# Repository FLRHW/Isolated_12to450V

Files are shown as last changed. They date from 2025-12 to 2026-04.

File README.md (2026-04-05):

<p align="center" width="100%">
  <a href="https://github.com/FLRHW/Isolated_12to450V/actions/workflows/ci.yaml">
    
  </a>
</p>

<p align="center" width="100%">
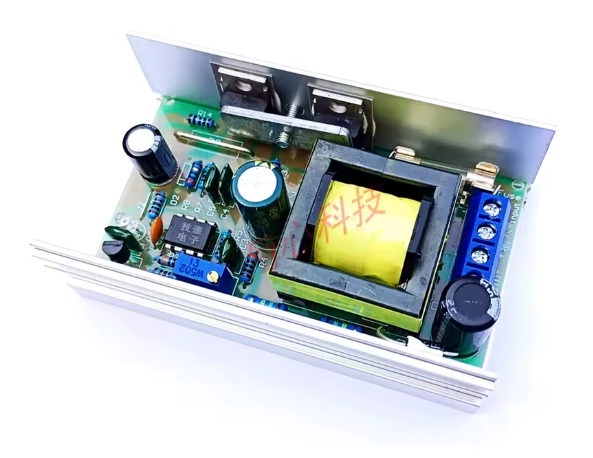
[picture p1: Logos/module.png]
    
</p>

***

<p align="center">
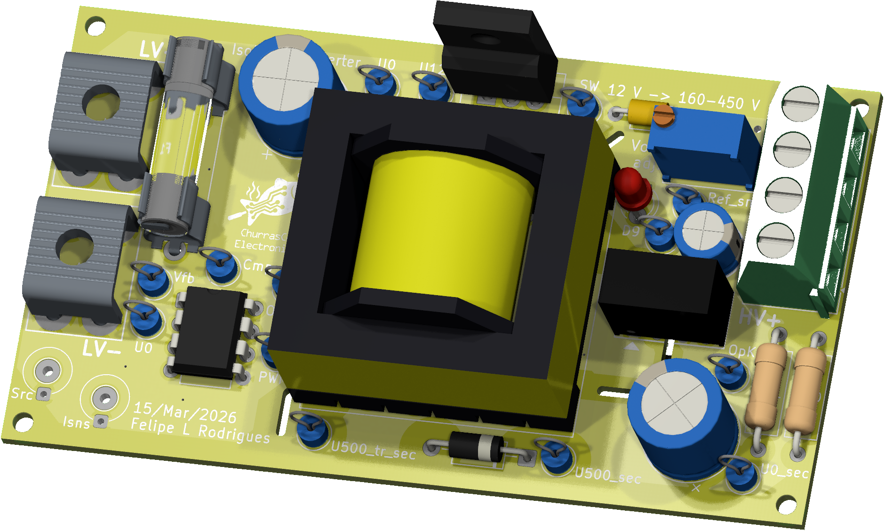
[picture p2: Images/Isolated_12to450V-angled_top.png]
3D Top Angled
  
&nbsp; &nbsp; &nbsp; &nbsp;
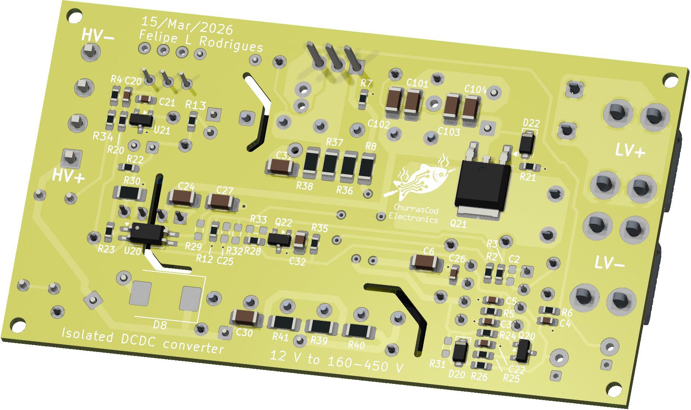
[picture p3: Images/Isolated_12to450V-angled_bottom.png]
3D Bottom Angled
  
</p>

***

# **Isolated step-up module**
This repository contains KiCad schematic and PCB layout of a step-up module prototype, isolated, capable of producing outputs in the range of 160 V to 450 V from a 12 V supply.

## Project overview
This project documents the conversion of a commercial non-isolated step-up module originally purchased from AliExpress into isolated.

## Origin and scope
Original hardware: generic module purchased from AliExpress (exact vendor and listing may change over time, the following terms can help finding similar modules: "70W DC-DC 12V 24V To 200V-450V Voltage Adjustable Boost Power Converter Nixie Clock Tube Amplifier Capacitor Charging").  

Redesigned hardware: new schematic and PCB layout, but several parts from the original module have been reused (controller, transformer, connector, fuse and its holder, power MOSFET, output diode, trim-pot, power resistors and electrolytic capacitors). 

Status: prototype, partially tested. Not affiliated with, endorsed by, or supported by the original manufacturer or seller.

Contents: KiCad design files and supporting documentation.

## Intended use
This repository is intended for:
* Educational use and study of the circuit
* Repair, modification, or replacement of compatible hardware
* Integration into hobby or research projects, subject to any third‑party IP that may apply in your jurisdiction. Users are responsible for checking any patent, copyright, or regulatory constraints that may apply to their own use

## License
The KiCad design files and documentation in this repository are released under the CERN Open Hardware Licence v2 – Permissive (CERN‑OHL‑P‑2.0). SPDX identifier: CERN-OHL-P-2.0 See the LICENSE file for the full legal text and conditions.  

In short and non‑legal terms, you are free to use, modify, manufacture, and distribute hardware based on these files, provided you respect attribution requirements and the terms in the license.

## Trademarks and third‑party rights
All product names, logos, and brands of the original module are the property of their respective owners and are not included or licensed here.  

Any reference to third‑party marks is purely descriptive and does not imply endorsement or affiliation.  

If you are the rights holder for the original hardware and have concerns about this documentation, please open an issue in the repository.

## Safety and disclaimer
* The author takes no responsibility for any injury, death or damage arising from the use, direct or indirect, of the design or otherwise any information from this repository
* You shall not build this or any prototype based on this design unless you are absolutely sure of your abilities dealing with this type of circuit
* High voltage can cause injury, death, or damage to equipment. Ensure appropriate protections and testing procedures are followed
* Use it at your own risk. Always review the schematic, layout, and component ratings before using it
* The design is provided as is, with no warranty of any kind

## Contributing
Contributions are welcome.

***

## DIRECTORY STRUCTURE
    │
    ├─ Computations       # Misc calculations
    ├─ HTML               # HTML files for generated webpage
    ├─ Images             # Pictures and renders
    │
    ├─ kibot_resources    # External resources for KiBot
    │  ├─ colors          # Color theme for KiCad
    │  ├─ fonts           # Fonts used in the project
    │  ├─ scripts         # External scripts used with KiBot
    │  └─ templates       # Templates for KiBot generated reports
    │
    ├─ kibot_yaml         # KiBot YAML config files
    ├─ KiRI               # KiRI (PCB diff viewer) files
    │
    ├─ lib                # KiCad footprint and symbol libraries
    │  ├─ 3d_models       # Component 3D models
    │  ├─ lib_fp          # Footprint libraries
    │  └─ lib_sym         # Symbol libraries
    │
    ├─ Logos              # Logos
    │
    ├─ Manufacturing      # Assembly and fabrication documents
    │  ├─ Assembly        # Assembly documents (BoM, pos, notes)
    │  │
    │  └─ Fabrication     # Fabrication documents (ZIP, notes)
    │     ├─ Drill Tables # CSV drill tables
    │     └─ Gerbers      # Gerbers
    │
    ├─ Reports            # Reports for ERC/DRC
    ├─ Schematic          # PDF of schematic
    ├─ Templates          # Title block templates
    └─ Testing
       └─ Testpoints      # Testpoints tables

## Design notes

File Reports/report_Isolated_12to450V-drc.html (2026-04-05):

Logo

(https://github.com/INTI-CMNB/KiBot/) | DRC report for Isolated_12to450V
| PCB: Isolated_12to450V Revision: 3.0.1 Date: 2026-04-05T18:37:05+0000 KiCad Version: 9.0.7 | Errors: 0 (+1 excluded) Warnings: 9 Total: 9 (+1 excluded)

Violations

Type | Description | Details
lib_footprint_issues | The current configuration does not include the footprint library 'Personal'. | @(109.601 mm, 81.026 mm): Footprint TP36
lib_footprint_issues | The current configuration does not include the footprint library 'Personal'. | @(151.003 mm, 66.294 mm): Footprint TR1
lib_footprint_issues | The current configuration does not include the footprint library 'Personal'. | @(111.633 mm, 68.326 mm): Footprint J21
lib_footprint_issues | The current configuration does not include the footprint library 'Personal'. | @(116.078 mm, 83.301861 mm): Footprint TP35
lib_footprint_issues | The current configuration does not include the footprint library 'Personal'. | @(147.828 mm, 48.768 mm): Footprint R9
lib_footprint_issues | The current configuration does not include the footprint library 'Personal'. | @(173.736 mm, 66.294 mm): Footprint Mod20
lib_footprint_issues | The current configuration does not include the footprint library 'Personal'. | @(111.633 mm, 52.451 mm): Footprint J20
lib_footprint_issues | The current configuration does not include the footprint library 'Personal'. | @(120.523 mm, 54.991 mm): Footprint F1
lib_footprint_mismatch | Footprint 'LED_D3.0mm' does not match copy in library 'LED_THT'. | @(168.021 mm, 54.864 mm): Footprint D9
courtyards_overlap | Courtyards overlap | @(189.0 mm, 42.027 mm): Footprint H2 @(185.928 mm, 61.816 mm): Footprint J1

Generated by KiBot (https://github.com/INTI-CMNB/KiBot/) v1.8.6

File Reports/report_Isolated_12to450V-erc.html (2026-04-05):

Logo

(https://github.com/INTI-CMNB/KiBot/) | ERC report for Isolated_12to450V
| Schematic: Isolated_12to450V Revision: 3.0.1 Date: 2026-04-05T18:37:03+0000 KiCad Version: 9.0.7 | Errors: 0 Warnings: 33 Total: 33

Sheet / (Isolated_12to450V.kicad_sch)

Type | Description | Details
lib_symbol_issues | The current configuration does not include the symbol library 'personal' | @(0.2286 mm, 0.9652 mm): Symbol P32 [Cosmetic_PWR]
lib_symbol_issues | The current configuration does not include the symbol library 'personal' | @(0.6604 mm, 1.1684 mm): Symbol P30 [Cosmetic_PWR]
lib_symbol_issues | The current configuration does not include the symbol library 'personal' | @(0.7874 mm, 1.1684 mm): Symbol P31 [Cosmetic_PWR]
footprint_link_issues | The current configuration does not include the footprint library 'Personal'. | @(1.3462 mm, 0.4572 mm): Symbol J20 [Screw_Terminal_01x01]
footprint_link_issues | The current configuration does not include the footprint library 'Personal'. | @(1.3462 mm, 0.6858 mm): Symbol J21 [Screw_Terminal_01x01]
lib_symbol_issues | The current configuration does not include the symbol library 'personal' | @(1.0668 mm, 1.1684 mm): Symbol P20 [Cosmetic_PWR]
footprint_link_issues | The current configuration does not include the footprint library 'Personal'. | @(1.5367 mm, 0.4572 mm): Symbol F1 [Fuse]
lib_symbol_issues | The current configuration does not include the symbol library 'personal' | @(1.1684 mm, 1.1684 mm): Symbol P21 [Cosmetic_PWR]
lib_symbol_issues | The current configuration does not include the symbol library 'personal' | @(1.5748 mm, 0.9144 mm): Symbol P24 [Cosmetic_PWR]
lib_symbol_issues | The current configuration does not include the symbol library 'personal' | @(1.8796 mm, 0.4318 mm): Symbol P26 [Cosmetic_PWR_SRC]
lib_symbol_issues | The current configuration does not include the symbol library 'personal' | @(1.5748 mm, 1.1684 mm): Symbol P106 [Cosmetic_PWR_SRC]
lib_symbol_issues | The current configuration does not include the symbol library 'personal' | @(1.3208 mm, 1.8288 mm): Symbol P27 [Cosmetic_PWR_SRC]
lib_symbol_issues | The current configuration does not include the symbol library 'personal' | @(1.8542 mm, 1.397 mm): Symbol U1 [UC3845]
lib_symbol_issues | The current configuration does not include the symbol library 'personal' | @(2.032 mm, 1.27 mm): Symbol P22 [Cosmetic_PWR]
lib_symbol_issues | The current configuration does not include the symbol library 'personal' | @(2.4638 mm, 0.8382 mm): Symbol P23 [Cosmetic_PWR]
lib_symbol_issues | The current configuration does not include the symbol library 'personal' | @(2.413 mm, 1.2446 mm): Symbol P105 [Cosmetic_PWR]
footprint_link_issues | The current configuration does not include the footprint library 'Personal'. | @(2.3114 mm, 1.6764 mm): Symbol TP35 [OscTestpoint]
lib_symbol_issues | The current configuration does not include the symbol library 'personal' | @(2.3114 mm, 1.6764 mm): Symbol TP35 [OscTestpoint]
lib_symbol_issues | The current configuration does not include the symbol library 'personal' | @(3.0988 mm, 0.5588 mm): Symbol P101 [Cosmetic_IN]
lib_symbol_issues | The current configuration does not include the symbol library 'personal' | @(2.9591 mm, 1.0922 mm): Symbol P102 [Cosmetic_OUT]
footprint_link_issues | The current configuration does not include the footprint library 'Personal'. | @(2.7178 mm, 1.6764 mm): Symbol TP36 [OscTestpoint]
lib_symbol_issues | The current configuration does not include the symbol library 'personal' | @(2.7178 mm, 1.6764 mm): Symbol TP36 [OscTestpoint]
footprint_link_issues | The current configuration does not include the footprint library 'Personal'. | @(3.2004 mm, 0.635 mm): Symbol TR1 [TR_12to450V_alixp_inv]
lib_symbol_issues | The current configuration does not include the symbol library 'personal' | @(3.2004 mm, 0.635 mm): Symbol TR1 [TR_12to450V_alixp_inv]
footprint_link_issues | The current configuration does not include the footprint library 'Personal'. | @(2.8194 mm, 1.6637 mm): Symbol R9 [R]
footprint_link_issues | The current configuration does not include the footprint library 'Personal'. | @(3.2004 mm, 1.0668 mm): Symbol TR1 [TR_12to450V_alixp_inv]
lib_symbol_issues | The current configuration does not include the symbol library 'personal' | @(3.2004 mm, 1.0668 mm): Symbol TR1 [TR_12to450V_alixp_inv]
lib_symbol_issues | The current configuration does not include the symbol library 'personal' | @(2.921 mm, 1.905 mm): Symbol P25 [Cosmetic_PWR]
footprint_link_issues | The current configuration does not include the footprint library 'Personal'. | @(3.2004 mm, 1.9812 mm): Symbol Mod20 [WB____S-1W_long]
lib_symbol_issues | The current configuration does not include the symbol library 'personal' | @(3.2004 mm, 1.9812 mm): Symbol Mod20 [WB____S-1W_long]
lib_symbol_issues | The current configuration does not include the symbol library 'personal' | @(3.556 mm, 1.3716 mm): Symbol P8 [Cosmetic_PWR]
lib_symbol_issues | The current configuration does not include the symbol library 'personal' | @(3.7338 mm, 0.9906 mm): Symbol P28 [Cosmetic_PWR_SRC]
lib_symbol_issues | The current configuration does not include the symbol library 'personal' | @(3.5052 mm, 1.905 mm): Symbol P29 [Cosmetic_PWR_SRC]

Generated by KiBot (https://github.com/INTI-CMNB/KiBot/) v1.8.6

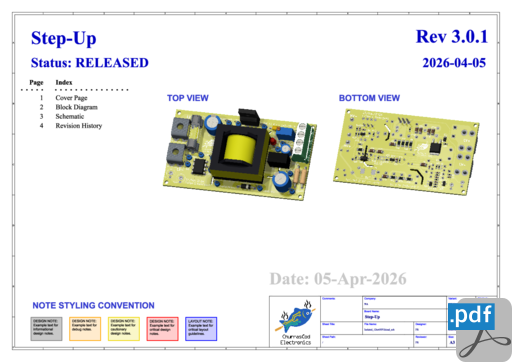
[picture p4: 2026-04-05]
HTML/images/cat_pdf_schematic_Isolated_12to450V-schematic.png

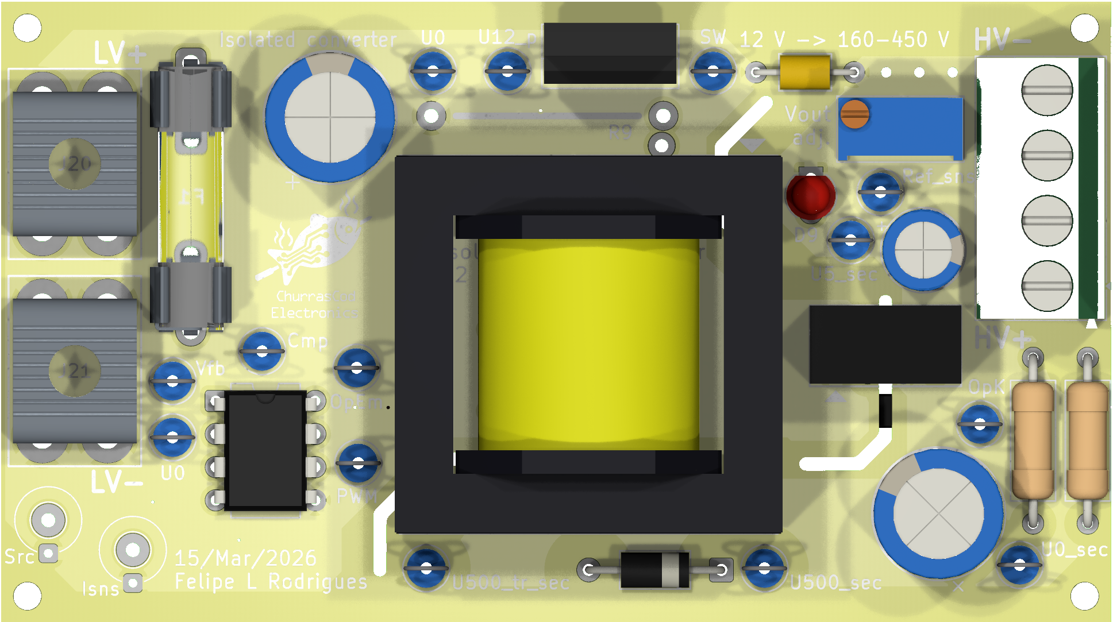
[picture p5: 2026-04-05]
Images/Isolated_12to450V-top.png

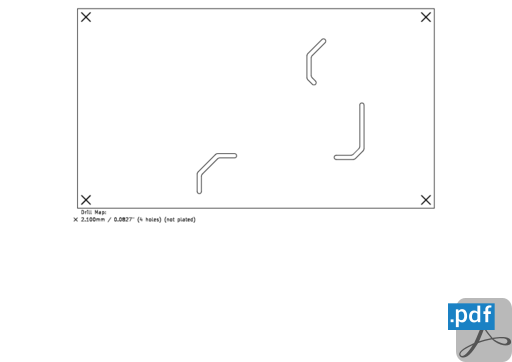
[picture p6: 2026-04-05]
HTML/images/cat_pdf_drill_map_Isolated_12to450V-NPTH_drill_map.png

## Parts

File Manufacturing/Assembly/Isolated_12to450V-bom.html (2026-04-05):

 | Bill of Materials
 | Schematic: Isolated_12to450V Variant: RELEASED Revision: 3.0.1 Date: 2026-02-07 KiCad Version: 9.0.7+1 | Component Groups: 50 Component Count: 75 (per PCB) Fitted Components: 68 (per PCB) Number of PCBs: 1 Total Components: 68 (for 1 PCBs)
Row | Quantity Per PCB | References | Value | Datasheet | Footprint | Description | Manufacturer | Manufacturer Part Number | Supplier Part Number
1 | 1 | C21 | 100p | ~ | C_0603_1608Metric_Pad1.08x0.95mm_HandSolder | Unpolarized capacitor
2 | 1 | C30 | 220p | ~ | C_1206_3216Metric_Pad1.33x1.80mm_HandSolder | Unpolarized capacitor
3 | 2 | C3 C4 | 1n | ~ | C_0603_1608Metric_Pad1.08x0.95mm_HandSolder | Unpolarized capacitor
4 | 1 | C29 | 1.5n | ~ | C_Axial_L3.8mm_D2.6mm_P7.50mm_Horizontal | Unpolarized capacitor
5 | 1 | C31 | 2.7n | ~ | C_1206_3216Metric_Pad1.33x1.80mm_HandSolder | Unpolarized capacitor
6 | 1 | C22 | 10n | ~ | C_0603_1608Metric_Pad1.08x0.95mm_HandSolder | Unpolarized capacitor
7 | 3 | C5 C20 C26 | 100n | ~ | C_0603_1608Metric_Pad1.08x0.95mm_HandSolder | Unpolarized capacitor
8 | 1 | C32 | 1u | ~ | C_0805_2012Metric_Pad1.18x1.45mm_HandSolder | Unpolarized capacitor
9 | 7 | C6 C24 C27 C101 C102 C103 C104 | 4.7u | ~ | C_1206_3216Metric_Pad1.33x1.80mm_HandSolder | Unpolarized capacitor
10 | 1 | C8 | 10u | ~ | CP_Radial_D10.0mm_P5.00mm | Polarized capacitor
11 | 1 | C28 | 100u | ~ | CP_Radial_D6.3mm_P2.50mm | Polarized capacitor
12 | 1 | C7 | 1000u | ~ | CP_Radial_D10.0mm_P5.00mm | Polarized capacitor
13 | 1 | D22 | BZT52B15 | https://diotec.com/tl_files/diotec/files/pdf/datasheets/bzt52b2v4.pdf | D_SOD-123F | 500mW Zener Diode, SOD-123F
14 | 1 | D9 | LED | ~ | LED_D3.0mm | Light emitting diode
15 | 1 | D20 | PMEG4010CEH | https://assets.nexperia.com/documents/data-sheet/PMEG4010CEH_PMEG4010CEJ.pdf | D_SOD-123F | 40V, 1A very low Vf MEGA Schottky barrier rectifier, SOD-123F
16 | 1 | D4 | UF4007 | ~ | D_A-405_P10.16mm_Horizontal | Diode
17 | 1 | F1 | 10A | ~ | Fuse_5x20mm_w_holders | Fuse
18 | 1 | J1 | Screw_Terminal_01x04 | ~ | TerminalBlock_Phoenix_MKDS-1,5-4_1x04_P5.00mm_Horizontal | Generic screw terminal, single row, 01x04, script generated (kicad-library-utils/schlib/autogen/connector/) |  | Generic screw terminal
19 | 2 | J20 J21 | T44007 | ~ | T44007 | Generic screw terminal, single row, 01x01, script generated (kicad-library-utils/schlib/autogen/connector/) |  | T44007
20 | 1 | Mod20 | WB2405S-1W |  | WB___S-1W |  | RLT | WB2405S-1W
21 | 1 | Q20 | BC817 | https://www.onsemi.com/pub/Collateral/BC818-D.pdf | SOT-23 | 0.8A Ic, 45V Vce, NPN Transistor, SOT-23
22 | 1 | Q22 | BC857 | https://www.onsemi.com/pub/Collateral/BC860-D.pdf | SOT-23 | 0.1A Ic, 45V Vce, PNP Transistor, SOT-23
23 | 1 | Q1 | HY1707 | ~ | TO-220F-3_Vertical | N-MOSFET transistor, gate/drain/source
24 | 1 | Q21 | SUD50P06-15 | https://www.vishay.com/docs/68940/sud50p06.pdf | TO-252-2 | -50A Id, -60V Vds, TrenchFET P-Channel Power MOSFET, 15mOhm Ron, 165nC Qg, -55 to 150 °C, TO-252-2
25 | 2 | R28 R34 | 0 | ~ | R_0603_1608Metric_Pad0.98x0.95mm_HandSolder | Resistor
26 | 1 | R9 | 13.7m | ~ | Shunt_alixp_module | Resistor
27 | 1 | R8 | 20 | ~ | R_1206_3216Metric_Pad1.30x1.75mm_HandSolder | Resistor
28 | 3 | R36 R37 R38 | 33 | ~ | R_1206_3216Metric_Pad1.30x1.75mm_HandSolder | Resistor
29 | 1 | R23 | 470 | ~ | R_0603_1608Metric_Pad0.98x0.95mm_HandSolder | Resistor |  | RC0603FR-07470RL
30 | 4 | R30 R39 R40 R41 | 470 | ~ | R_1206_3216Metric_Pad1.30x1.75mm_HandSolder | Resistor |  | RC1206JR-07470RL
31 | 2 | R6 R13 | 1k | ~ | R_0603_1608Metric_Pad0.98x0.95mm_HandSolder | Resistor
32 | 1 | R12 | 1k2 | ~ | R_0603_1608Metric_Pad0.98x0.95mm_HandSolder | Resistor
33 | 2 | R22 R25 | 2k2 | ~ | R_0603_1608Metric_Pad0.98x0.95mm_HandSolder | Resistor
34 | 1 | R4 | 2k7 | ~ | R_0603_1608Metric_Pad0.98x0.95mm_HandSolder | Resistor
35 | 2 | R24 R26 | 4k7 | ~ | R_0603_1608Metric_Pad0.98x0.95mm_HandSolder | Resistor
36 | 1 | R7 | 5k1 | ~ | R_0603_1608Metric_Pad0.98x0.95mm_HandSolder | Resistor
37 | 3 | R2 R3 R21 | 10k | ~ | R_0603_1608Metric_Pad0.98x0.95mm_HandSolder | Resistor
38 | 1 | R5 | 15k | ~ | R_0603_1608Metric_Pad0.98x0.95mm_HandSolder | Resistor
39 | 2 | R20 R35 | 100k | ~ | R_0603_1608Metric_Pad0.98x0.95mm_HandSolder | Resistor
40 | 2 | R10 R11 | 240k | ~ | R_Axial_DIN0309_L9.0mm_D3.2mm_P12.70mm_Horizontal | Resistor
41 | 1 | TR1 | Custom_1:19.5 |  | Tr12to450V_Alixp
42 | 1 | U20 | TCMT1108 | http://www.vishay.com/docs/83510/tcmt1100.pdf | SOP-4_4.4x2.6mm_P1.27mm | Optocoupler, Vce 70V, CTR 130-260%, Viso 3750V (RMS), SOP-4 |  | TCMT1108
43 | 1 | U21 | TL431M |  | SOT-23 | Shunt Regulator, SOT-23 | FOSAN | TL431M-0.3%-6AF
44 | 1 | U1 | UC3845 |  | DIP-8_W7.62mm
45 | 1 | VR1 | 5k | ~ | Potentiometer_Bourns_3296W_Vertical | Trim-potentiometer
Row | Quantity Per PCB | References | Value | Datasheet | Footprint | Description | Manufacturer | Manufacturer Part Number | Supplier Part Number
1 | 2 | C2 C25 | 1n | ~ | C_0603_1608Metric_Pad1.08x0.95mm_HandSolder | Unpolarized capacitor
2 | 1 | D8 | S15M | ~ | D_SMC | Diode
3 | 2 | R32 R33 | 0 | ~ | R_0603_1608Metric_Pad0.98x0.95mm_HandSolder | Resistor
4 | 1 | R29 | 1k | ~ | R_0603_1608Metric_Pad0.98x0.95mm_HandSolder | Resistor
5 | 1 | R31 | 2k2 | ~ | R_0603_1608Metric_Pad0.98x0.95mm_HandSolder | Resistor
Color reference for columns:
KiCad Fields (default)
Generated Fields
User Fields
Empty Fields

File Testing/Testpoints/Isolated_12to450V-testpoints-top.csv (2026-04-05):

Ref. | Net | X [mm] | Y [mm]
TP9 | Sec_ref_sns | 71.76 | 89.03
TP10 | Sec_OpK | 79.38 | 71.25
TP20 | SW | 58.93 | 98.30
TP23 | PWM | 31.76 | 68.26
TP24 | Vfb | 17.53 | 74.55
TP25 | Comp | 24.39 | 76.83
TP26 | OpEm | 31.63 | 75.56
TP27 | U500_sec | 62.87 | 60.20
TP28 | U0_sec | 82.43 | 60.45
TP30 | U500_tr_sec | 36.96 | 60.20
TP31 | U12_p | 43.19 | 98.30
TP32 | U0 | 17.53 | 70.23
TP33 | U0 | 37.47 | 98.30
TP34 | U5_sec | 69.48 | 85.34
TP35 | Isns,U0 | 14.48 | 60.34
TP36 | Src,U0 | 8.01 | 62.61

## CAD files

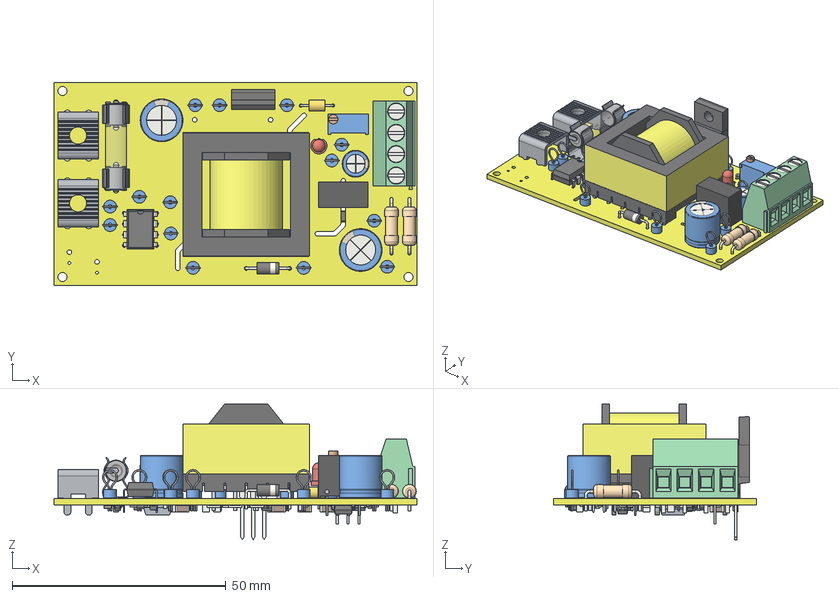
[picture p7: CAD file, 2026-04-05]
3D/Isolated_12to450V.step
85.0 x 47.5 x 31.8 mm
R_Axial_DIN0309_L9.0mm_D3.2mm_P12.70mm_Horizontal x 2
Trafo_12to450V_module
TestPoint_Loop_D3.50mm_Drill0.9mm_Beaded x 14
C_Axial_L3.8mm_D2.6mm_P7.50mm_Horizontal
TerminalBlock_Phoenix_MKDS-1,5-4_1x04_P5.00mm_Horizontal
T44007_base x 2
CP_Radial_D10.0mm_P5.00mm x 2
TO-220F-3_Vertical
WB____S-1W
CP_Radial_D6.3mm_P2.50mm
DIP-8_W7.62mm
Potentiometer_Bourns_3296W_Vertical
Endcaps
Glass_body
fuse_holder x 2
D_A-405_P10.16mm_Horizontal
LED_D3.0mm
C_0603_1608Metric x 7
R_1206_3216Metric x 8
C_1206_3216Metric x 9
Isolated_12to450V 1.39.1
R_0603_1608Metric x 18
SOT-23 x 3
D_SOD-123F x 2
SOP-4_4.4x2.6mm_P1.27mm
C_0805_2012Metric
kibot_cr949vfv_PCB

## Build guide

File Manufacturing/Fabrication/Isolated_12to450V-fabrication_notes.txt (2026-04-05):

FABRICATION NOTES (UNLESS OTHERWISE SPECIFIED)

1)	FABRICATE PER IPC-6012A CLASS 2.

2)	OUTLINE DEFINED IN SEPARATE GERBER FILE WITH
	"Edge_Cuts.GBR" SUFFIX.

	DIMENSIONS SHOWN ON THIS DRAWING ARE FOR REFERENCE ONLY.

3)	SEE SEPARATE DRILL FILES WITH ".DRL" SUFFIX 
	FOR HOLE LOCATIONS.

	SELECTED HOLE LOCATIONS SHOWN ON THIS DRAWING 
	ARE FOR REFERENCE ONLY.

4)	SURFACE FINISH: HAL LEAD-FREE

5)	SOLDERMASK ON BOTH SIDES OF THE BOARD SHALL 
	BE LPI, COLOR YELLOW.

6)	SILK SCREEN LEGEND TO BE APPLIED PER LAYER 
	STACKUP USING WHITE NON-CONDUCTIVE EPOXY INK.

7)	ALL VIAS ARE TENTED ON BOTH SIDES UNLESS 
	SOLDERMASK OPENED IN GERBER.

8)	VENDOR SHOULD FOLLOW ROHS COMPLIANT PROCESS 
	AND Pb FREE FOR MANUFACTURING

9)	PCB MATERIAL REQUIREMENTS:

	A.	FLAMMABILITY RATING MUST MEET OR EXCEED 
		UL94V-0 REQUIREMENTS.
	B.	Tg 170 C OR EQUIVALENT.
	C.	EQUIVALENT MATERIAL SHALL BE RoHS COMPLIANT, 
		HALOGEN FREE AND APPROVED BY BUYER.

10)	DESIGN GEOMETRY MINIMUM FEATURE SIZES:

	BOARD SIZE				85.000 × 47.540 mm
	BOARD THICKNESS		1.600 mm
	TRACE WIDTH			0.300 mm
	TRACE TO TRACE		0.020 mm
	MIN. HOLE (PTH)			0.250 mm
	MIN. HOLE (NPTH)		2.100 mm
	ANNULAR RING			0.150 mm
	COPPER TO HOLE		0.200 mm
	COPPER TO EDGE		0.250 mm
	HOLE TO HOLE			0.254 mm

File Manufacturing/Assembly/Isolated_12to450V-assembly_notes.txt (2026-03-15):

ASSEMBLY NOTES (UNLESS OTHERWISE SPECIFIED)

1)	DO NOT POPULATE PARTS MARKED WITH A RED CROSS.

2)	IF CONFLICTING INFORMATION IS FOUND BETWEEN THE ASSEMBLY
	FILE AND BOM, BOM SHOULD BE USED AS THE MAIN SOURCE.

3)	DOT/CHAMFER/TRIANGLE/CROSS IDENTIFY PIN #1 LOCATION.

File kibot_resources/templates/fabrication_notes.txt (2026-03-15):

FABRICATION NOTES (UNLESS OTHERWISE SPECIFIED)

1)	FABRICATE PER IPC-6012A CLASS 2.

2)	OUTLINE DEFINED IN SEPARATE GERBER FILE WITH
	"Edge_Cuts.GBR" SUFFIX.

	DIMENSIONS SHOWN ON THIS DRAWING ARE FOR REFERENCE ONLY.

3)	SEE SEPARATE DRILL FILES WITH ".DRL" SUFFIX 
	FOR HOLE LOCATIONS.

	SELECTED HOLE LOCATIONS SHOWN ON THIS DRAWING 
	ARE FOR REFERENCE ONLY.

4)	SURFACE FINISH: ${pcb_finish_cap}

5)	SOLDERMASK ON BOTH SIDES OF THE BOARD SHALL 
	BE LPI, COLOR ${solder_mask_color_text_cap}.

6)	SILK SCREEN LEGEND TO BE APPLIED PER LAYER 
	STACKUP USING ${silk_screen_color_text_cap} NON-CONDUCTIVE EPOXY INK.

7)	ALL VIAS ARE TENTED ON BOTH SIDES UNLESS 
	SOLDERMASK OPENED IN GERBER.

8)	VENDOR SHOULD FOLLOW ROHS COMPLIANT PROCESS 
	AND Pb FREE FOR MANUFACTURING

9)	PCB MATERIAL REQUIREMENTS:

	A.	FLAMMABILITY RATING MUST MEET OR EXCEED 
		UL94V-0 REQUIREMENTS.
	B.	Tg 170 C OR EQUIVALENT.
	C.	EQUIVALENT MATERIAL SHALL BE RoHS COMPLIANT, 
		HALOGEN FREE AND APPROVED BY BUYER.

10)	DESIGN GEOMETRY MINIMUM FEATURE SIZES:

	BOARD SIZE				${bb_w_mm} × ${bb_h_mm} mm
	BOARD THICKNESS		${thickness_mm} mm
	TRACE WIDTH			${track_mm} mm
	TRACE TO TRACE		${clearance_mm} mm
	MIN. HOLE (PTH)			${drill_pth_real_mm} mm
	MIN. HOLE (NPTH)		${drill_npth_real_mm} mm
	ANNULAR RING			${oar_mm} mm
	COPPER TO HOLE		${c2h_mm} mm
	COPPER TO EDGE		${c2e_mm} mm
	HOLE TO HOLE			${h2h_mm} mm
#?stackup and impedance_controlled

#?stackup and impedance_controlled
11)	REFER TO IMPEDANCE TABLE FOR IMPEDANCE CONTROL REQUIREMENTS.
#?stackup and impedance_controlled

#?stackup and impedance_controlled
12)	CONFIRM SPACE WIDTHS AND SPACINGS.

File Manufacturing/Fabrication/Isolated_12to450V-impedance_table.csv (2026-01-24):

Transmission Line | Impedance [ohms] | Tolerance [ohms] | Layer | Trace Width [mm] | Gap [mm] | Ref. Layers
NA | - | - | - | - | - | -

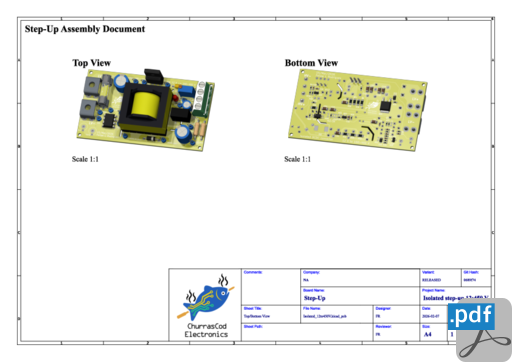
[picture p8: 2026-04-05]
HTML/images/cat_pdf_assembly_Isolated_12to450V-assembly.png

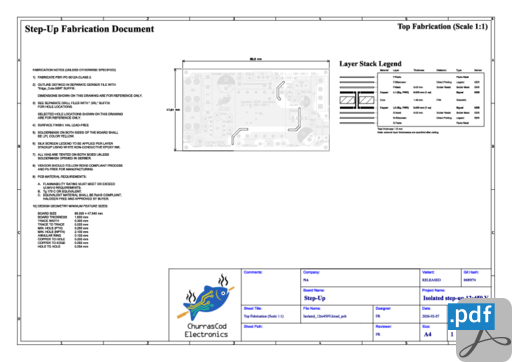
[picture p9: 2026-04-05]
HTML/images/cat_pdf_fabrication_Isolated_12to450V-fabrication.png

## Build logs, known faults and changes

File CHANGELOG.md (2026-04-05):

# Changelog

## [Unreleased]

## [3.0.1] - 2026-04-05

### Added power on LED

Updated manufacturing docs
Added some MPNs so different parts are on separate BOM lines

## [3.0.0] - 2026-03-15

### C3 and R15 updated for shorter dead time

R26 increased to reduce artificial ramp
R31 added as alternative for artificial ramp
C4 updated to 1 nF
C20, C21 and R20 updated (slower compensation)
R3 increased (gain = 1 on error amp.)
C2 not fitted (secondary side compensation only)
D23 removed
Default optocoupler supply swapped R29->R28
R32 and R34 added to facilitate testing
Added snubber accross Q1 and D4
Enlarged R8, C6, C24 and C27 footprints
Silk typos (HV+/HV-) and R9 footprint fixed
Decreased R23 to prevent overvoltage at low load
Soft start circuit moved to primary side
Added D9 to support series connected modules
Added MLCCs in parallel with C7 to improve decoupling 

## [2.0.0] - 2026-02-07

### Added R29 as feed-forward option

Isolated primary ("LV") and secondary ("HV") sides
Updated reverse polarity protection (based on P-channel MOSFET)
Added dedicated connectors for supply input
Replaced C6 (100 uF elco -> 4.7 uF + 100 nF MLCCs)
Added C25 to support testing
Replaced packages (U1: DIP-8 -> SOIC-8; U21: TO-92 -> SOT-23)
Replaced U20 (SH816 -> TCMT1108)
Replaced Q20 (2N2222 -> BC817)
Reworked slope compensation
Updated F1 footprint and 3D model
Added part number to D4
Updated Mod20 decoupling and added R30 as load
Added testpoints
Added clearance rules

## [1.0.0] - 2026-01-24

### Cloned non-isolated design revision 1.1.0 as a working base.

Updated R10 and R11 to 240 kΩ (cloned design incorrectly used 140 kΩ).
Updated U1 to UC3845 (cloned design incorrectly used UC3843).
Reworked feedback loop to include opto-coupler while keeping the same reference on both sides to facilitate testing / reuse of original board.
Added two options of slope compensation / ramp injection (from U1 RT_CT pin and from U1 OUTPUT pin).
Adjusted R2 to 10 kΩ, R3 to 5 kΩ and C2 to 1 nF to improve behaviour (output swaps from bursts to 0 % duty periodically).
Added soft-start (D21, R27 and C23).
Increased C5 to 100 nF.
Adjusted C4 to 1.5 nF and R6 to 1 kΩ (similar time constant) to facilitate ramp injection.
Updated parts placement where suitable to reuse existing layout and added an auxiliary perf-board to accomodate the new parts.

[Unreleased]: https://github.com/FLRHW/Isolated_12to450V/compare/3.0.1...HEAD

[3.0.1]: https://github.com/FLRHW/Isolated_12to450V/compare/3.0.0...3.0.1

[3.0.0]: https://github.com/FLRHW/Isolated_12to450V/compare/2.0.0...3.0.0

[2.0.0]: https://github.com/FLRHW/Isolated_12to450V/compare/1.0.0...2.0.0

[1.0.0]: https://github.com/FLRHW/Isolated_12to450V/compare/f8c9afb6a11647257dfa5ab046e95b1ec53fcfd7...1.0.0

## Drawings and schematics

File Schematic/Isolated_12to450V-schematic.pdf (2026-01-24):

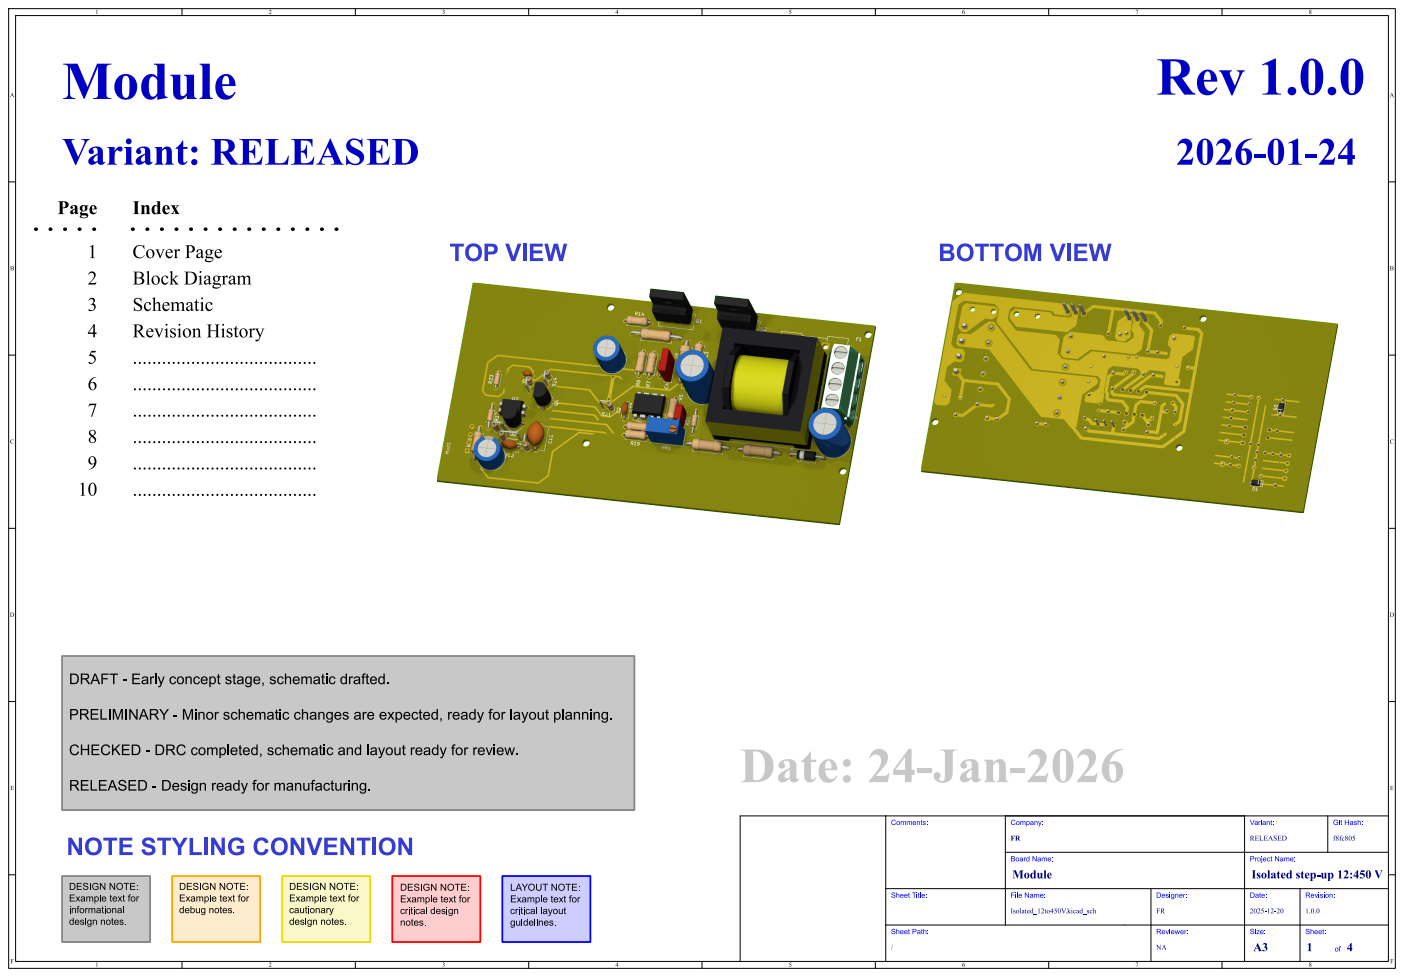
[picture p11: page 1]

PRELIMINARY - Minor schematic changes are expected, ready for layout planning.

CHECKED - DRC completed, schematic and layout ready for review.

RELEASED - Design ready for manufacturing.
NOTE STYLING CONVENTION

Revision: 1.0.0 Date: Project Name: 2025-12-20 Reviewer: NADesigner:

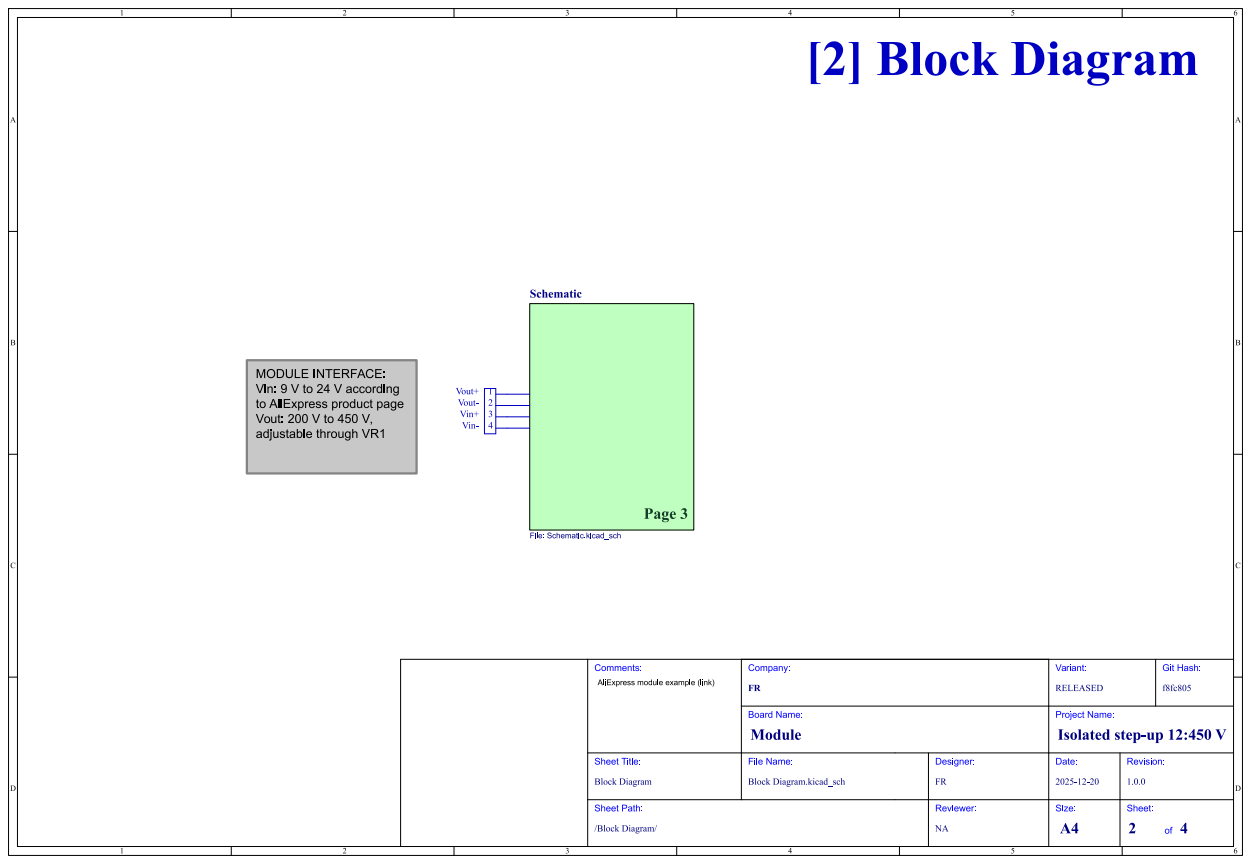
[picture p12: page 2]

File: Schematic.kicad_sch MODULE INTERFACE:
Vin: 9 V to 24 V according
to AliExpress product page
Vout: 200 V to 450 V,
adjustable through VR1

AliExpress module example (link) (https://www.aliexpress.com/item/1005006040711629.html)

/Block Diagram/ Sheet Path: Block Diagram

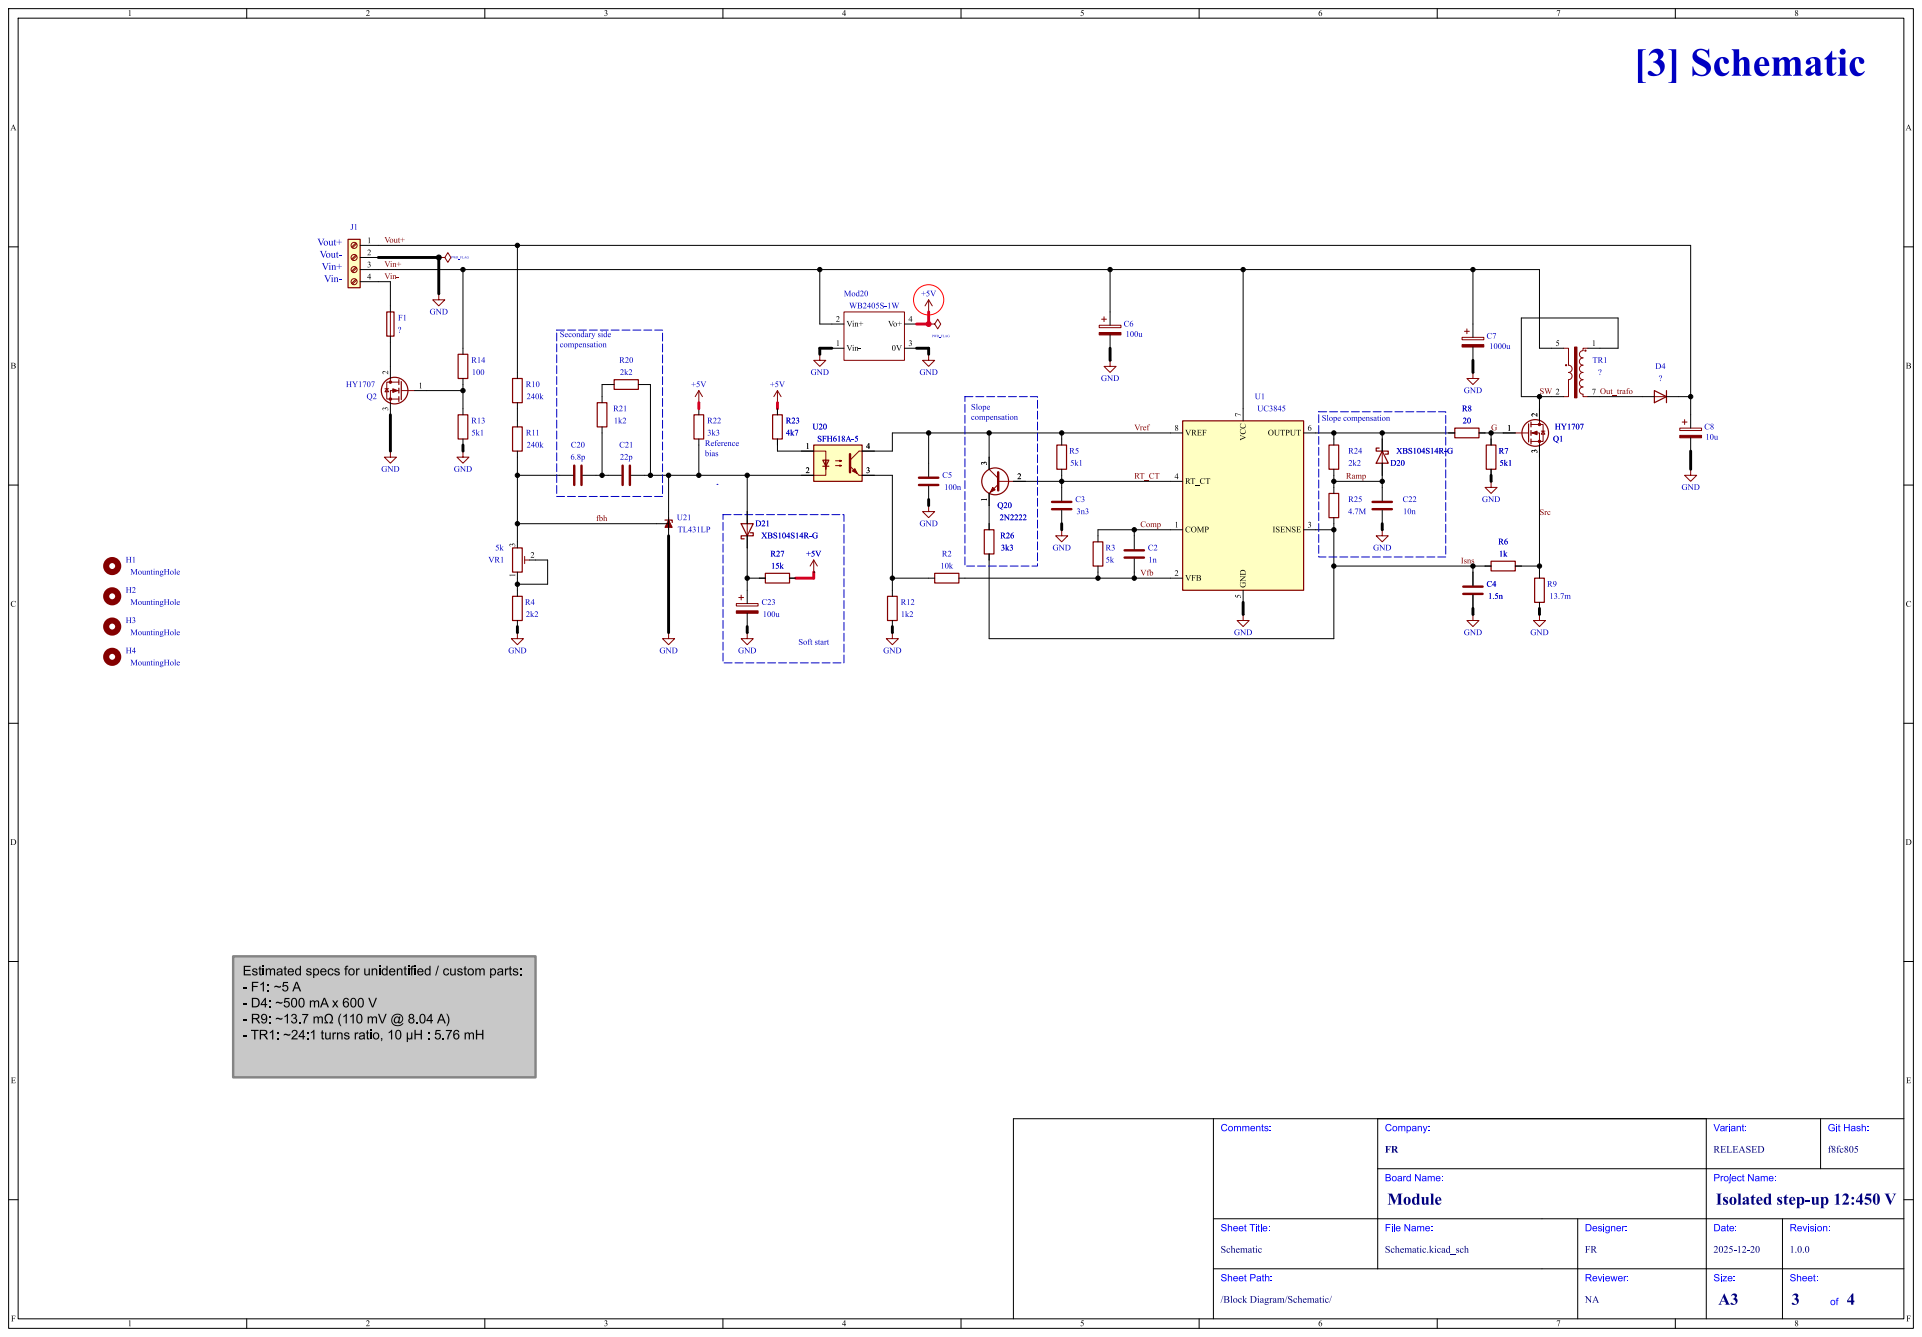
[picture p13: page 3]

- TR1: ~24:1 turns ratio, 10 þÿ¼H: 5.76 mH

Revision: 1.0.0 Date: Project Name: 2025-12-20 Reviewer: NADesigner:

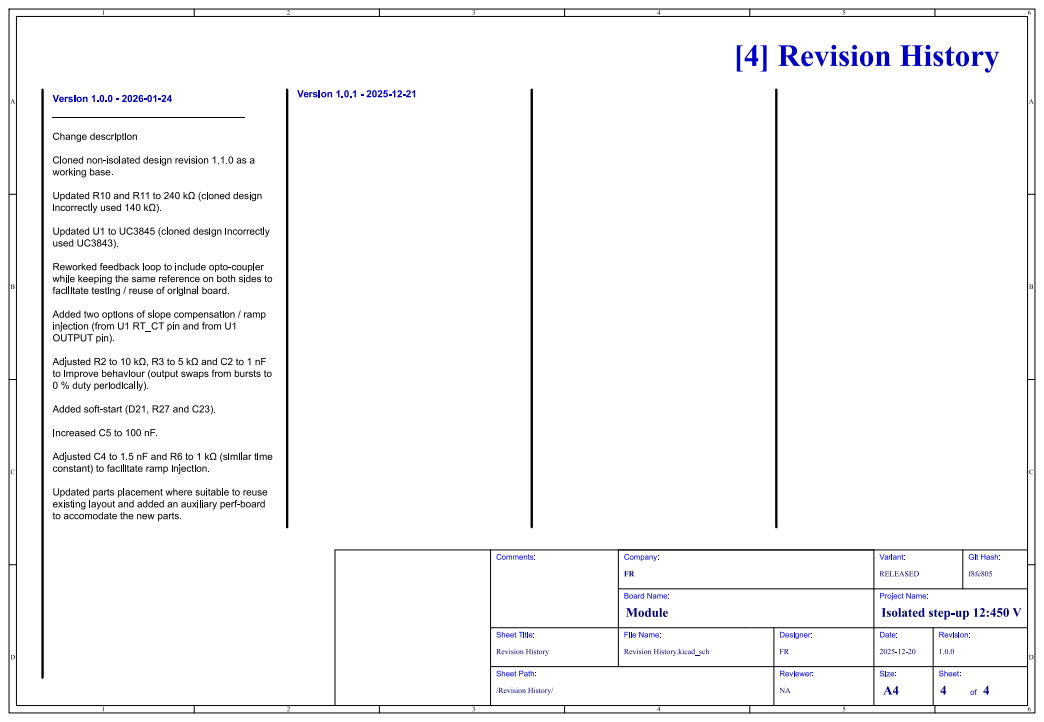
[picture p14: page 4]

Cloned non-isolated design revision 1.1.0 as a working base.

Updated R10 and R11 to 240 þÿk©(cloned design
incorrectly used 140 þÿk©).

Updated U1 to UC3845 (cloned design incorrectly
used UC3843).

Reworked feedback loop to include opto-coupler
while keeping the same reference on both sides to
facilitate testing / reuse of original board.

Added two options of slope compensation / ramp
injection (from U1 RT_CT pin and from U1
OUTPUT pin).

Adjusted R2 to 10 þÿk©, R3 to 5 þÿk©and C2 to 1 nF
to improve behaviour (output swaps from bursts to
0 % duty periodically).

Added soft-start (D21, R27 and C23).

Adjusted C4 to 1.5 nF and R6 to 1 þÿk©(similar time
constant) to facilitate ramp injection.

Updated parts placement where suitable to reuse
existing layout and added an auxiliary perf-board
to accomodate the new parts.

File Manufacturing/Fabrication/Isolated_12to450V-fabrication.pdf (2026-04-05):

# Top Fabrication (Scale 1:1) Step-Up Fabrication Document

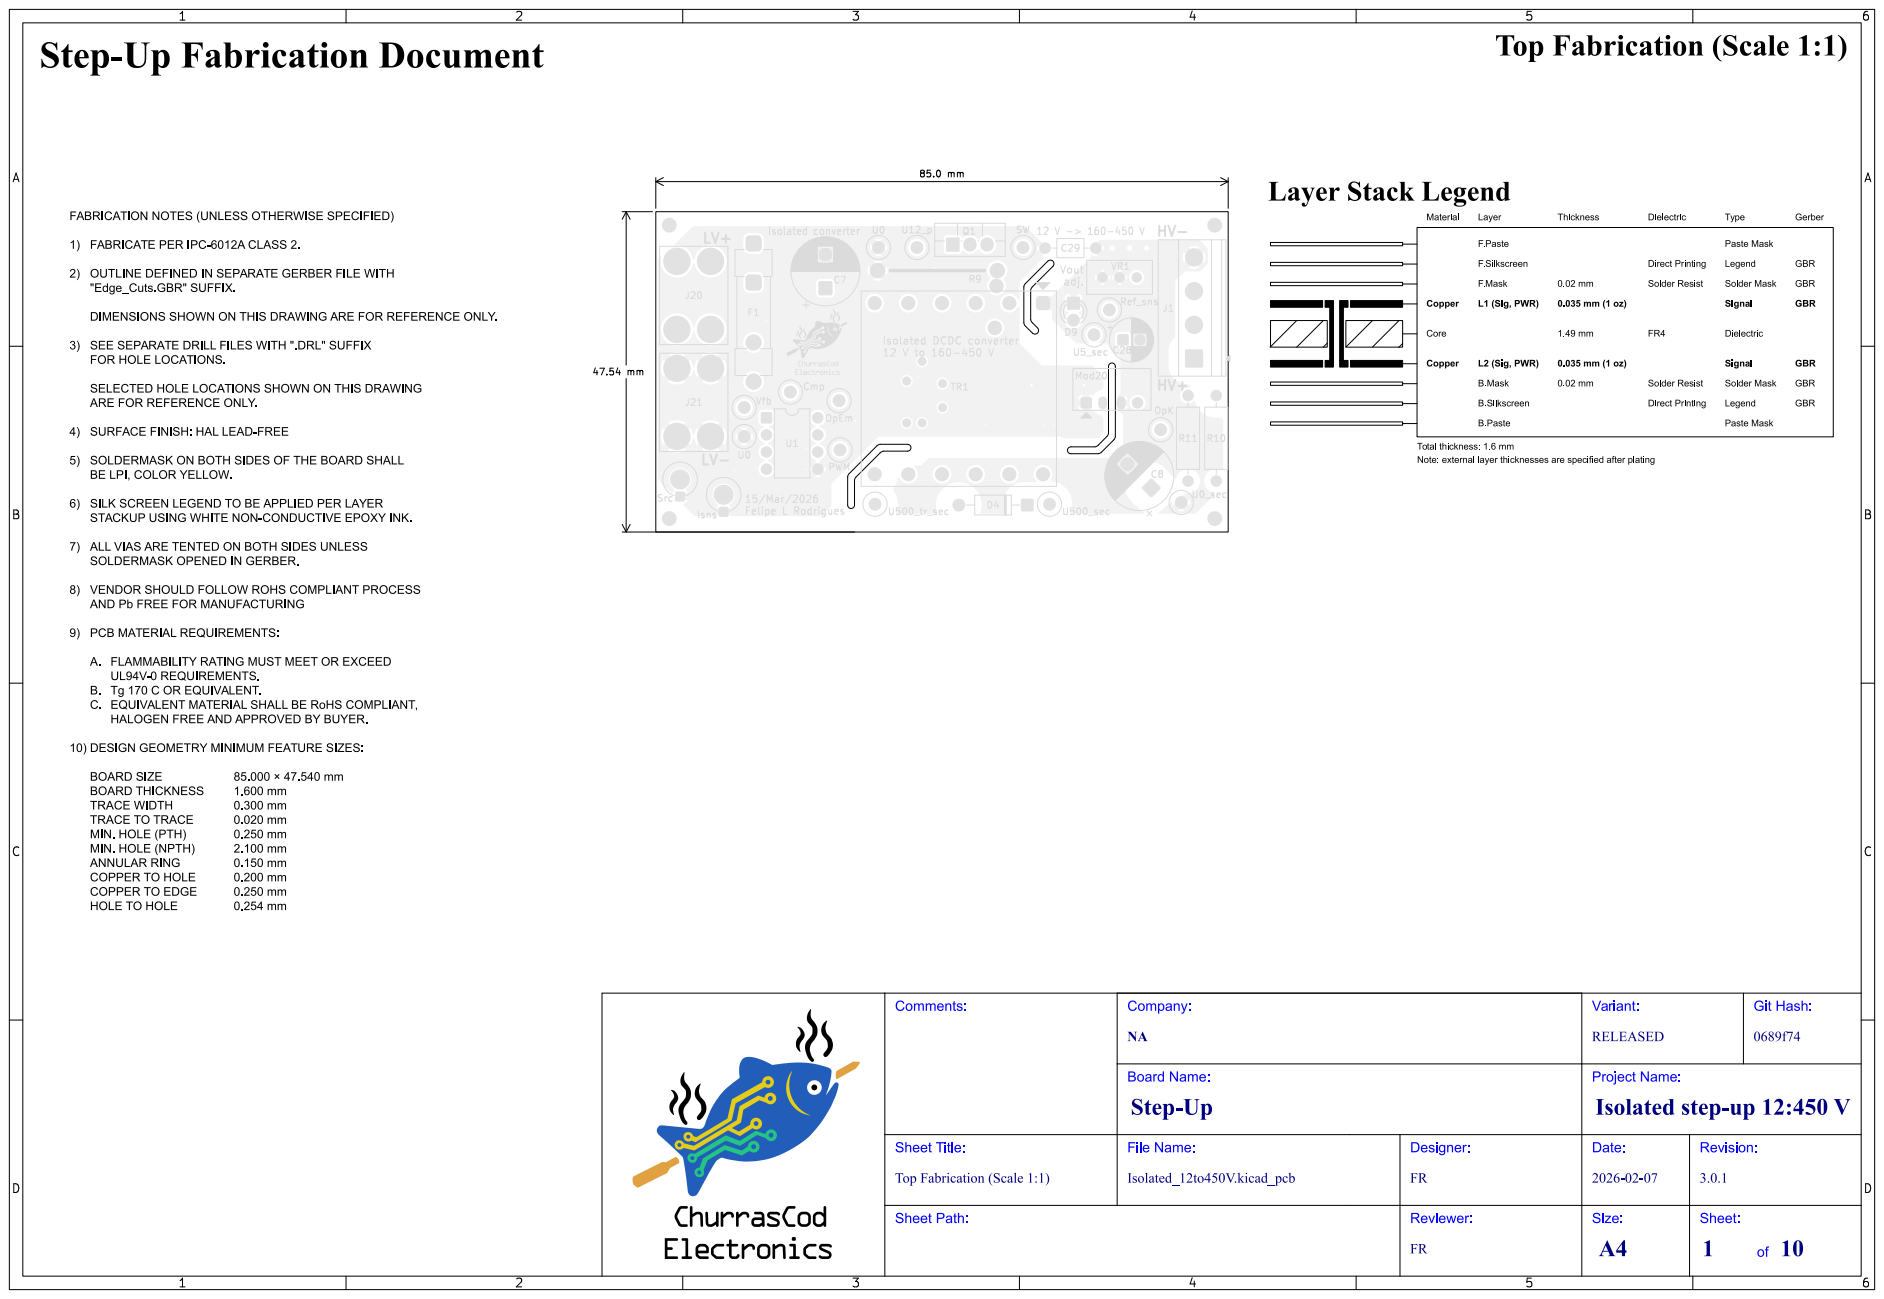
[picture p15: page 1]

# Bottom Fabrication (Scale 1:1) Step-Up Fabrication Document

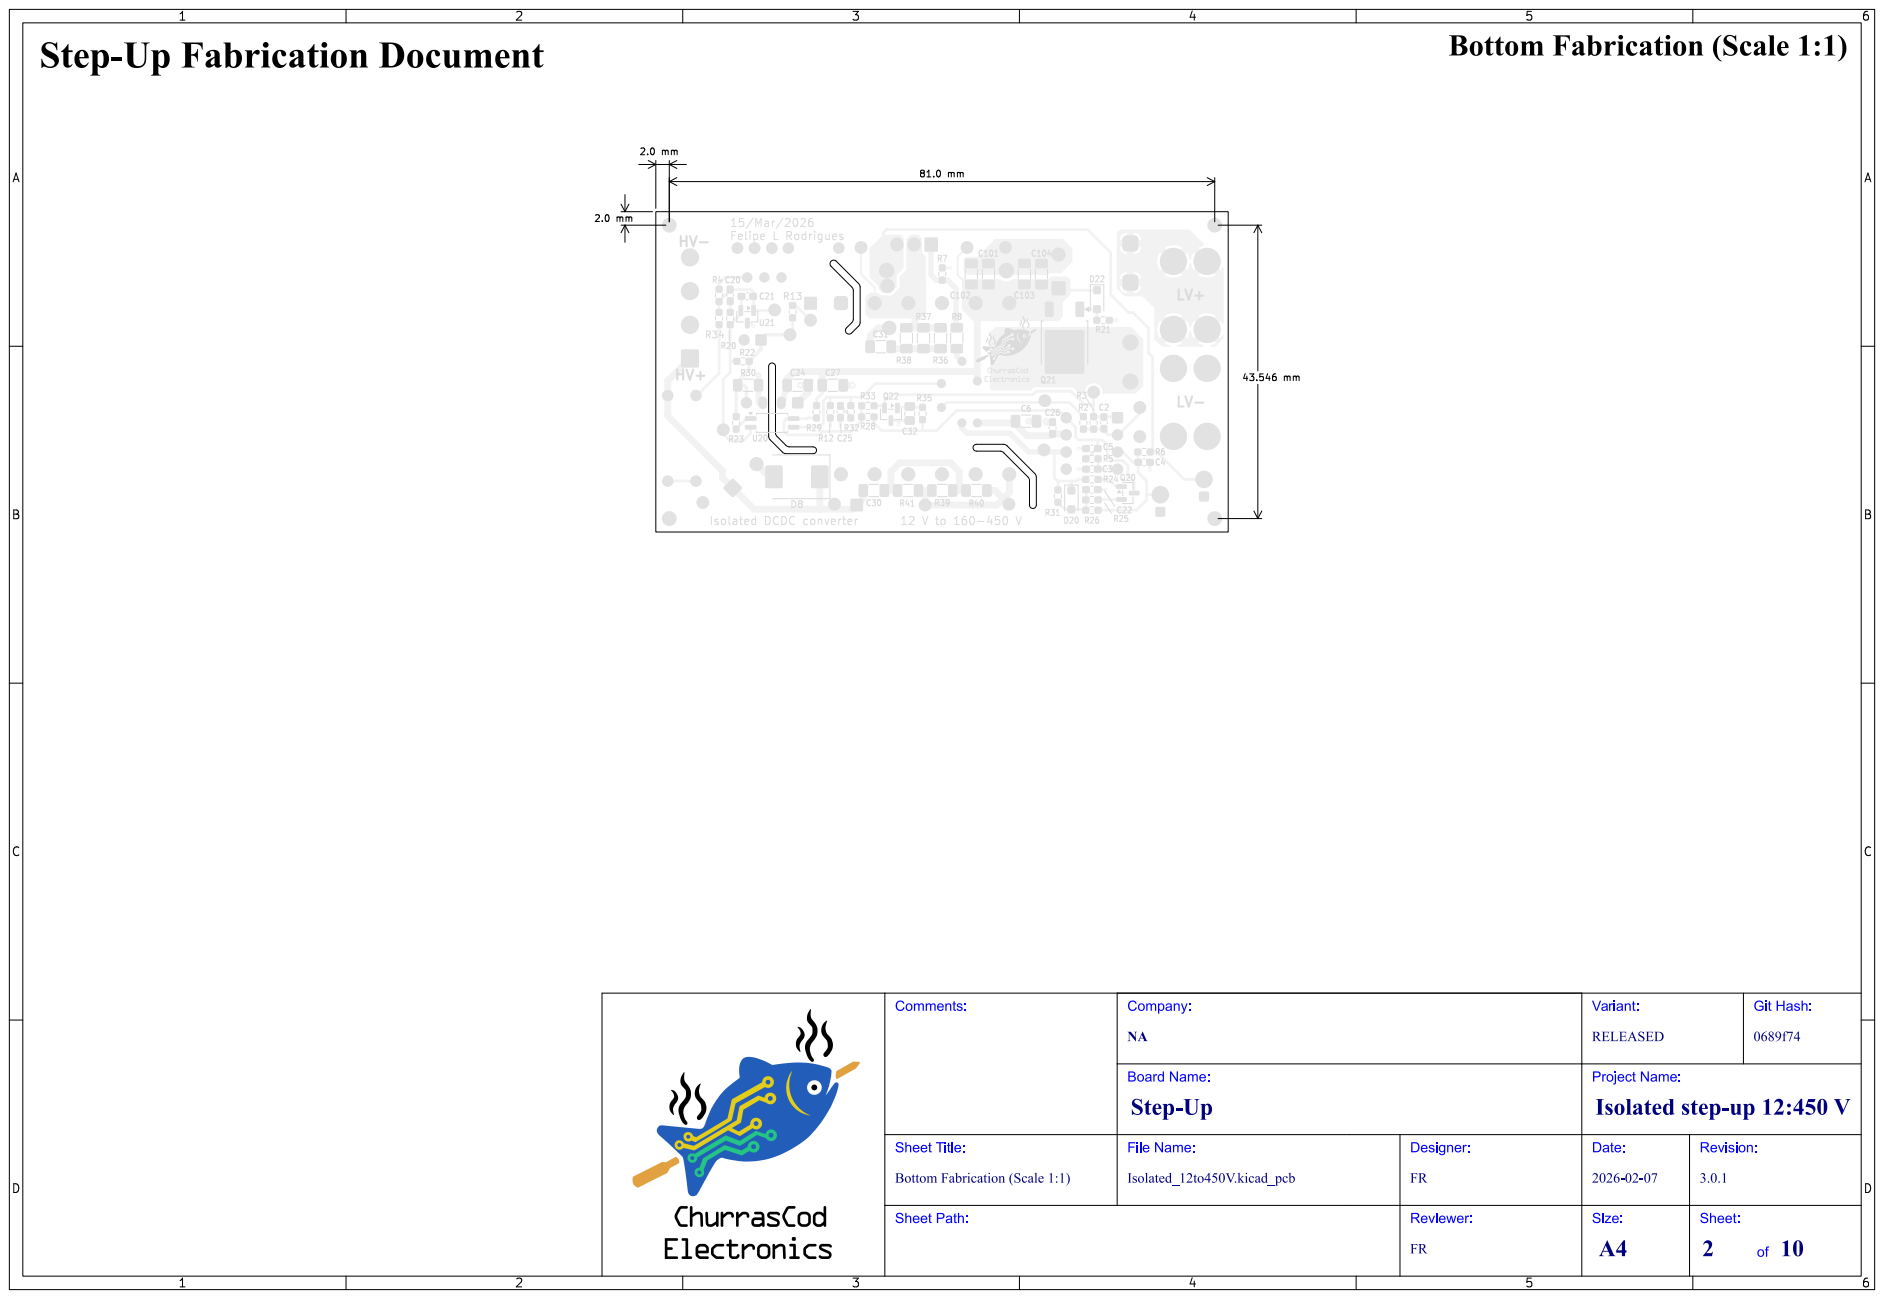
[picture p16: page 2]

# Drill Drawing L1 - L4 (Scale 1:1) Step-Up Fabrication Document

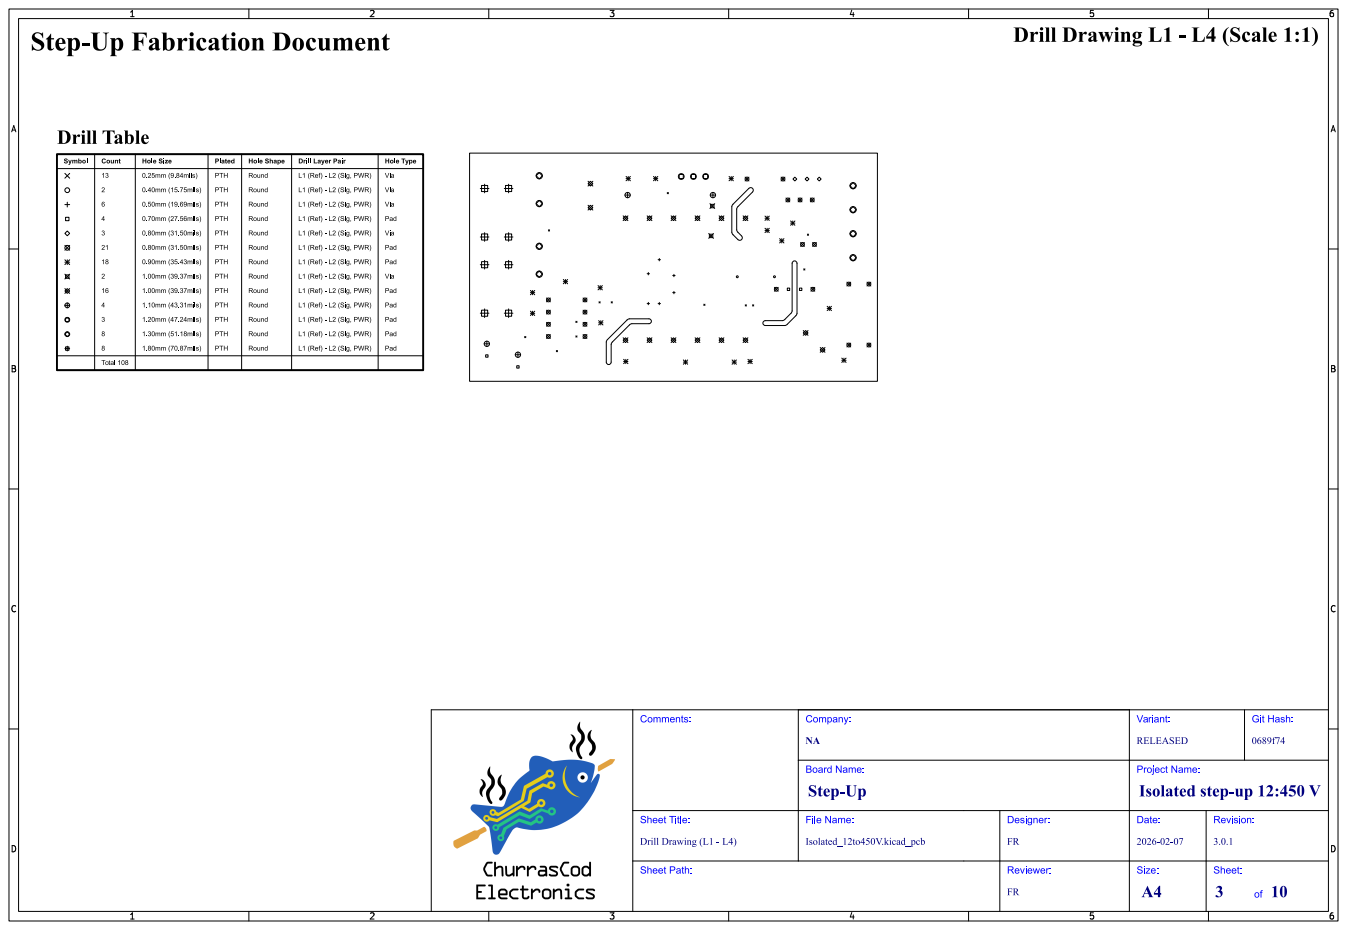
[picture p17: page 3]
Git; Hash:; Comments:; Drill Drawing (L1 - L4); Sheet Path:; Sheet Title:; File Name:; Step-Up; Isolated step-up 12:450 V; Company:; RELEASED; Variant:; Board Name:; Isolated_12to450V.kicad_pcb; Designer:; Reviewer:; Project Name:; Date:; Revision:; Size:; Sheet:

# Drill Drawing L1 - L4 (Scale 1:1) Step-Up Fabrication Document

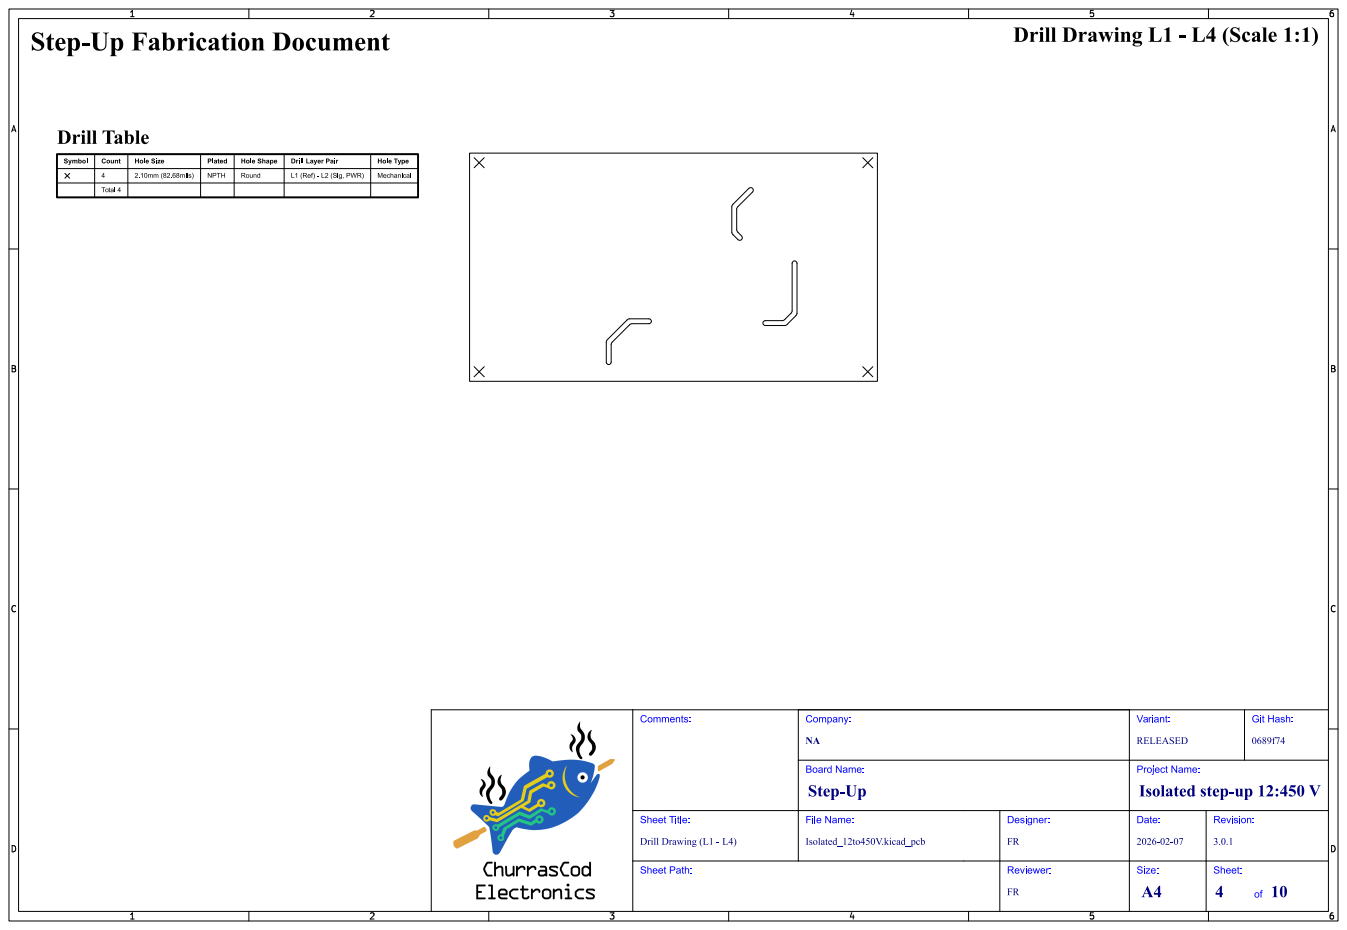
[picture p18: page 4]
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

# F.Cu (Scale 1:1) Step-Up Fabrication Document

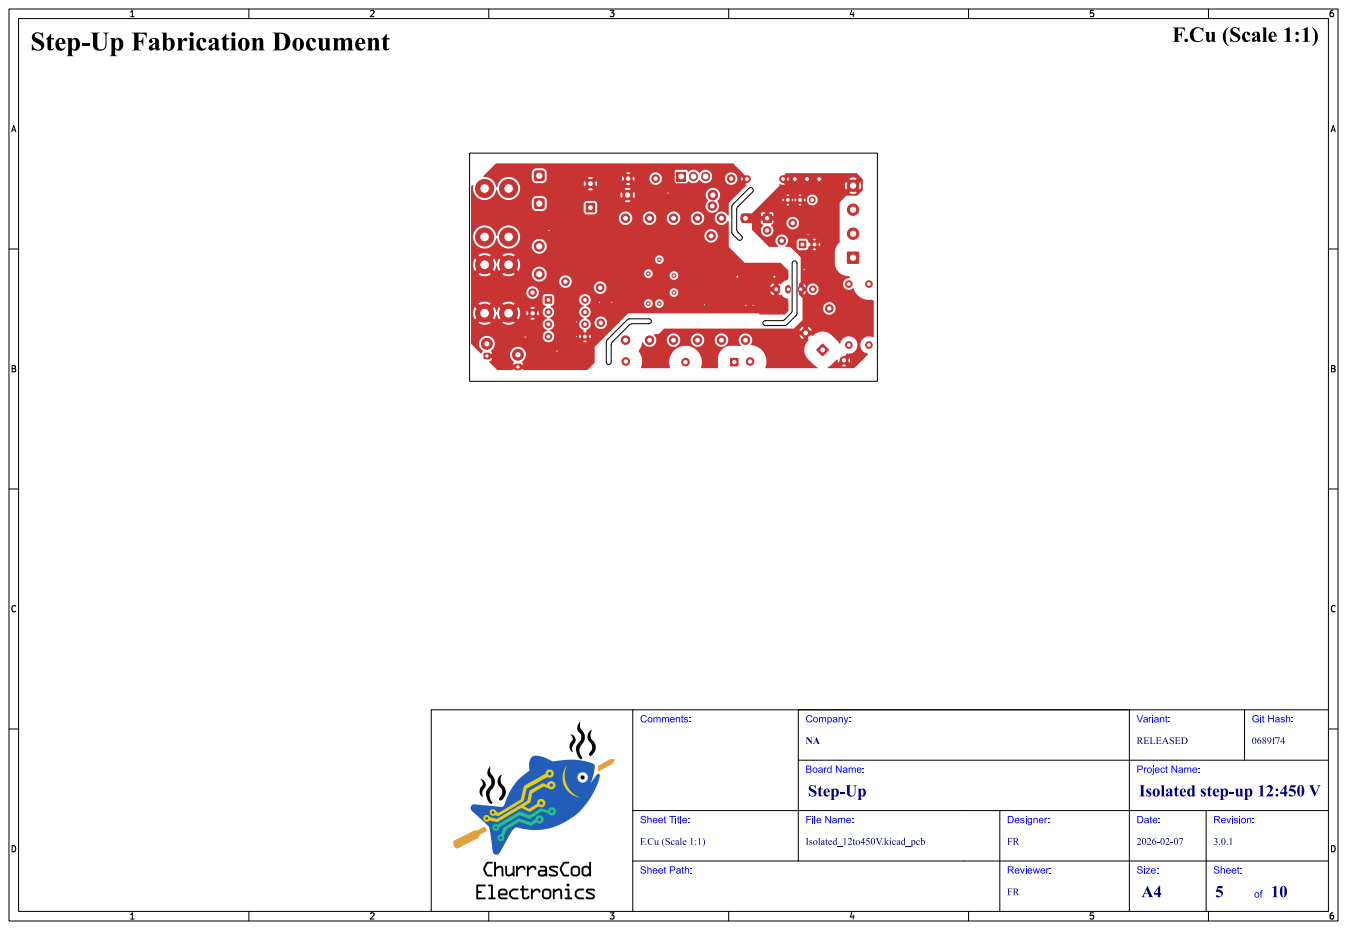
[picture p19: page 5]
Git; Hash:; Comments:; F.Cu (Scale 1:1); Sheet Path:; Sheet Title:; File Name:; Step-Up; Isolated step-up 12:450 V; Company:; RELEASED; Variant:; Board Name:; Isolated_12to450V.kicad_pcb; Designer:; Reviewer:; Project Name:; Date:; Revision:; Size:; Sheet:

# B.Cu (Scale 1:1) Step-Up Fabrication Document

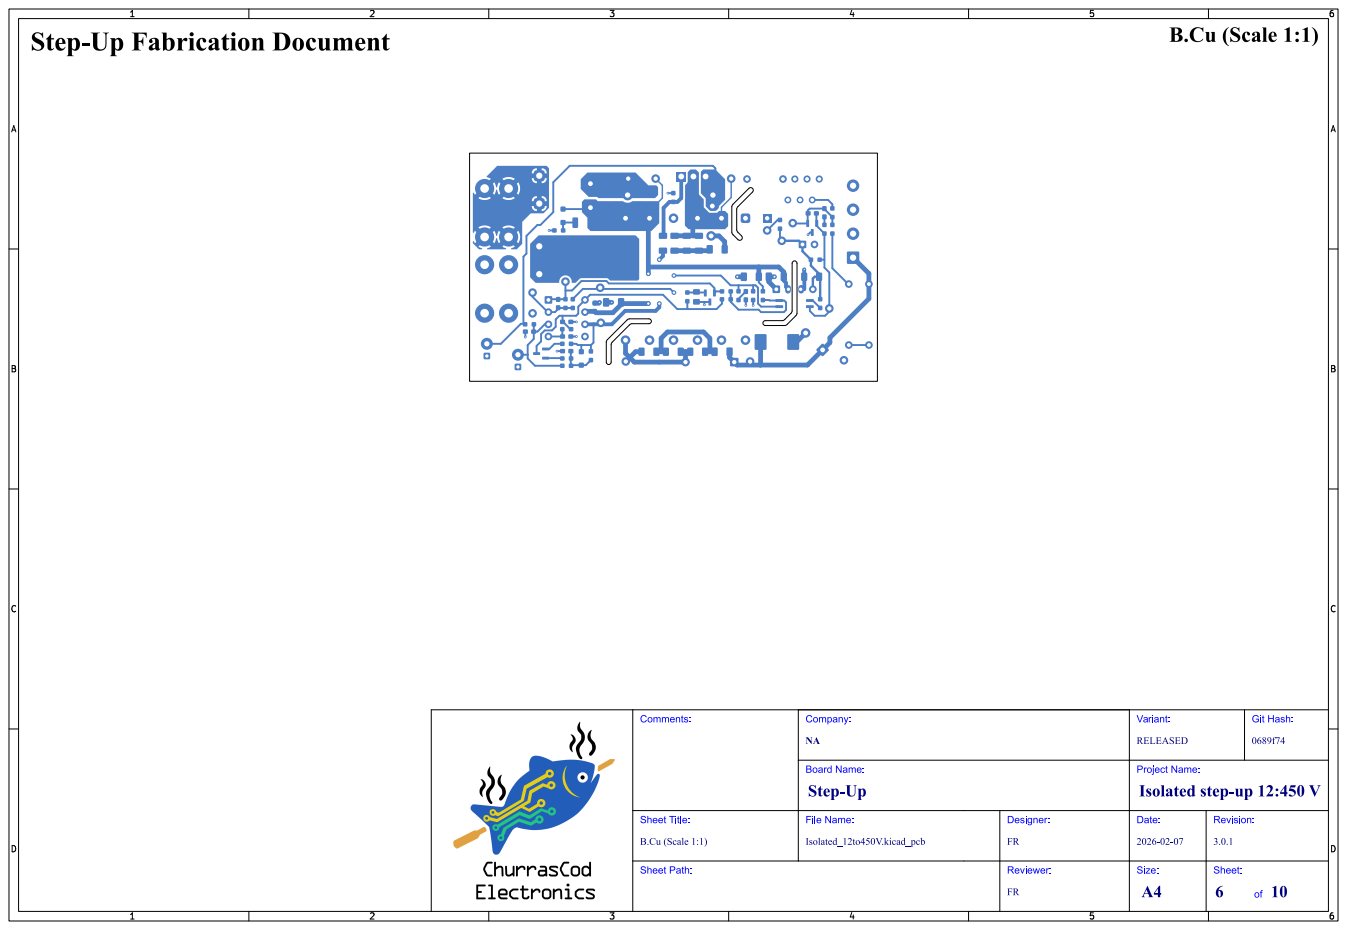
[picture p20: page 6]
Git; Hash:; Comments:; B.Cu (Scale 1:1); Sheet Path:; Sheet Title:; File Name:; Step-Up; Isolated step-up 12:450 V; Company:; RELEASED; Variant:; Board Name:; Isolated_12to450V.kicad_pcb; Designer:; Reviewer:; Project Name:; Date:; Revision:; Size:; Sheet:

# F.Mask (Scale 1:1) Step-Up Fabrication Document

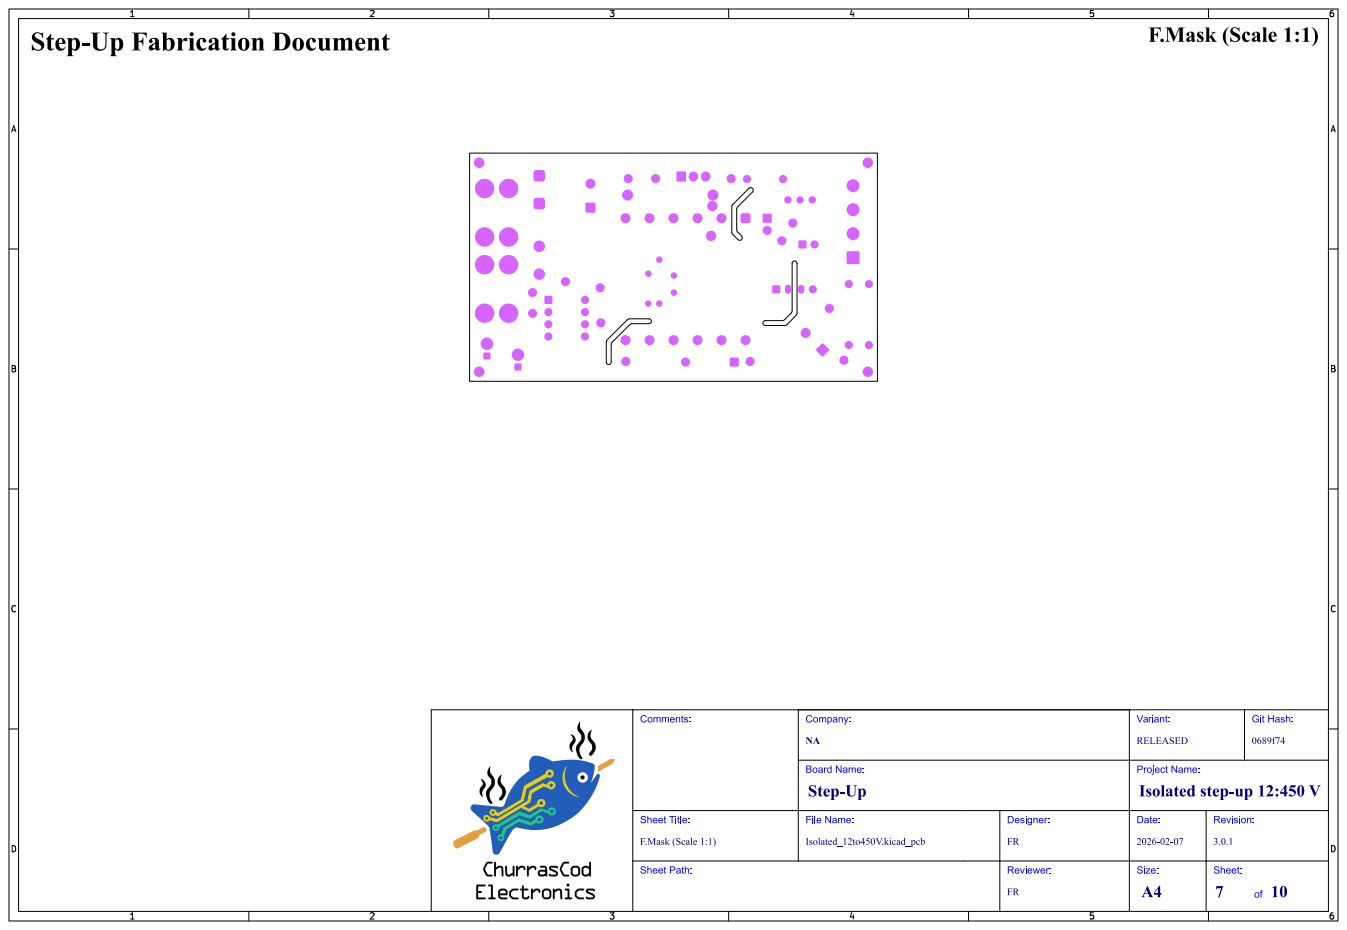
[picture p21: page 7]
Git; Hash:; Comments:; F.Mask (Scale 1:1); Sheet Path:; Sheet Title:; File Name:; Step-Up; Isolated step-up 12:450 V; Company:; RELEASED; Variant:; Board Name:; Isolated_12to450V.kicad_pcb; Designer:; Reviewer:; Project Name:; Date:; Revision:; Size:; Sheet:

# B.Mask (Scale 1:1) Step-Up Fabrication Document

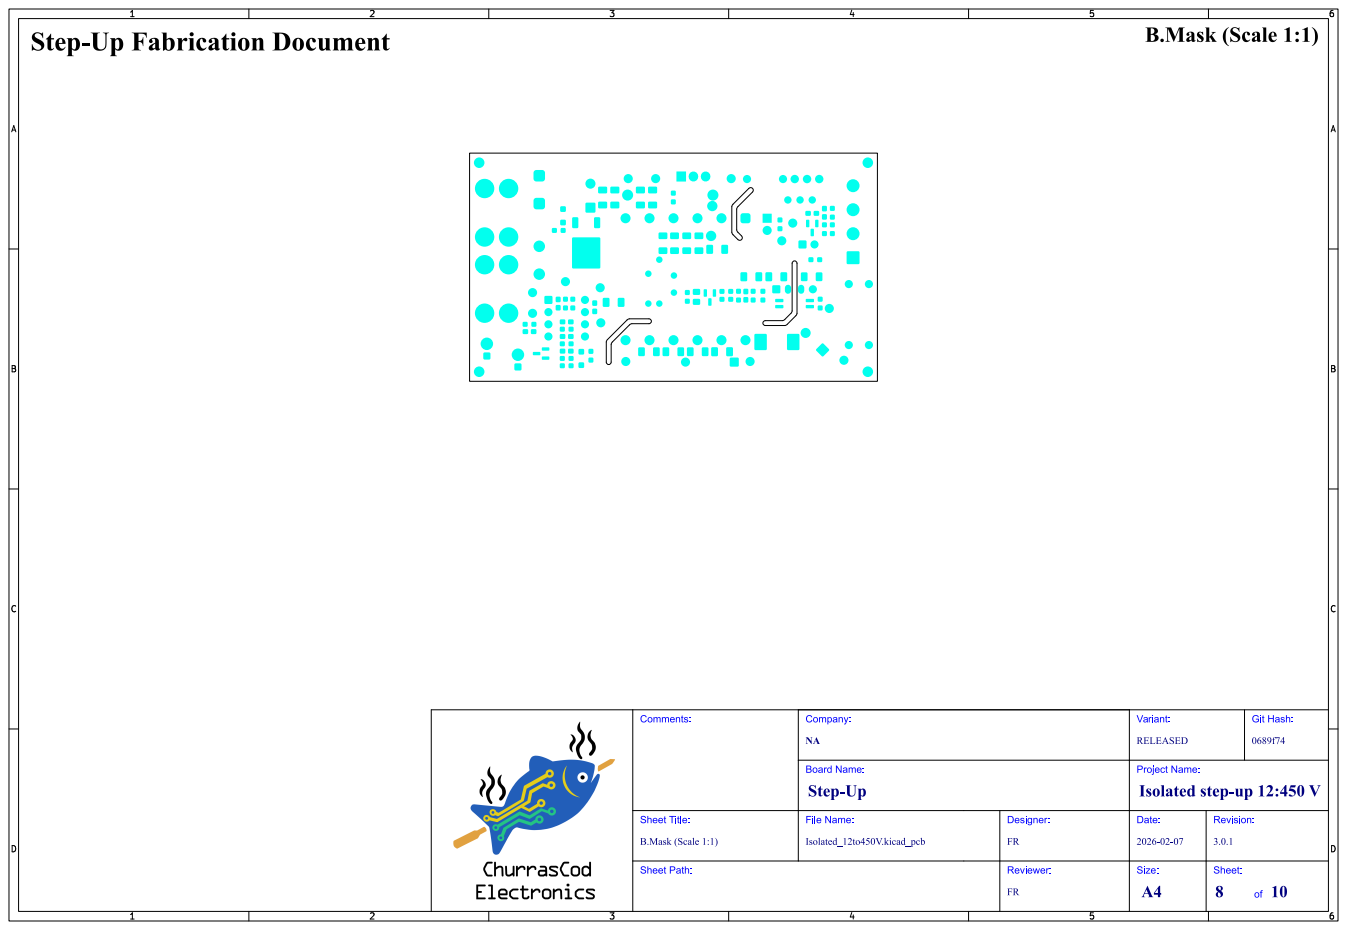
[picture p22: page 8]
Git; Hash:; Comments:; B.Mask (Scale 1:1); Sheet Path:; Sheet Title:; File Name:; Step-Up; Isolated step-up 12:450 V; Company:; RELEASED; Variant:; Board Name:; Isolated_12to450V.kicad_pcb; Designer:; Reviewer:; Project Name:; Date:; Revision:; Size:; Sheet:

# F.Silkscreen (Scale 1:1) Step-Up Fabrication Document


# B.Silkscreen (Scale 1:1) Step-Up Fabrication Document


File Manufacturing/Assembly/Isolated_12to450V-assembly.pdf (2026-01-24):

# Module Assembly Document

Git; Hash:; Comment 4; Comment 3; Comment 2; Comment 1; Comments:; Sheet Path:; Sheet Title:; File Name:; Module; Isolated step-up 12:450 V; Company:; RELEASED; Variant:; Board Name:; Isolated_12to450V.kicad_pcb; Designer:; Reviewer:; Project Name:; Date:; Revision:; Size:; Sheet:

Top/Bottom View

# Top Assembly (Scale 1:1)

# Module Assembly Document


# Bottom Assembly (Scale 1:1)

# Module Assembly Document

Git; Hash:; Comment 4; Comment 3; Comment 2; Comment 1; Comments:; Sheet Path:; Sheet Title:; File Name:; Module; Isolated step-up 12:450 V; Company:; RELEASED; Variant:; Board Name:; Isolated_12to450V.kicad_pcb; Designer:; Reviewer:; Project Name:; Date:; Revision:; Size:; Sheet:; XBS104S14R-G

Bottom Assembly (Scale 1:1)










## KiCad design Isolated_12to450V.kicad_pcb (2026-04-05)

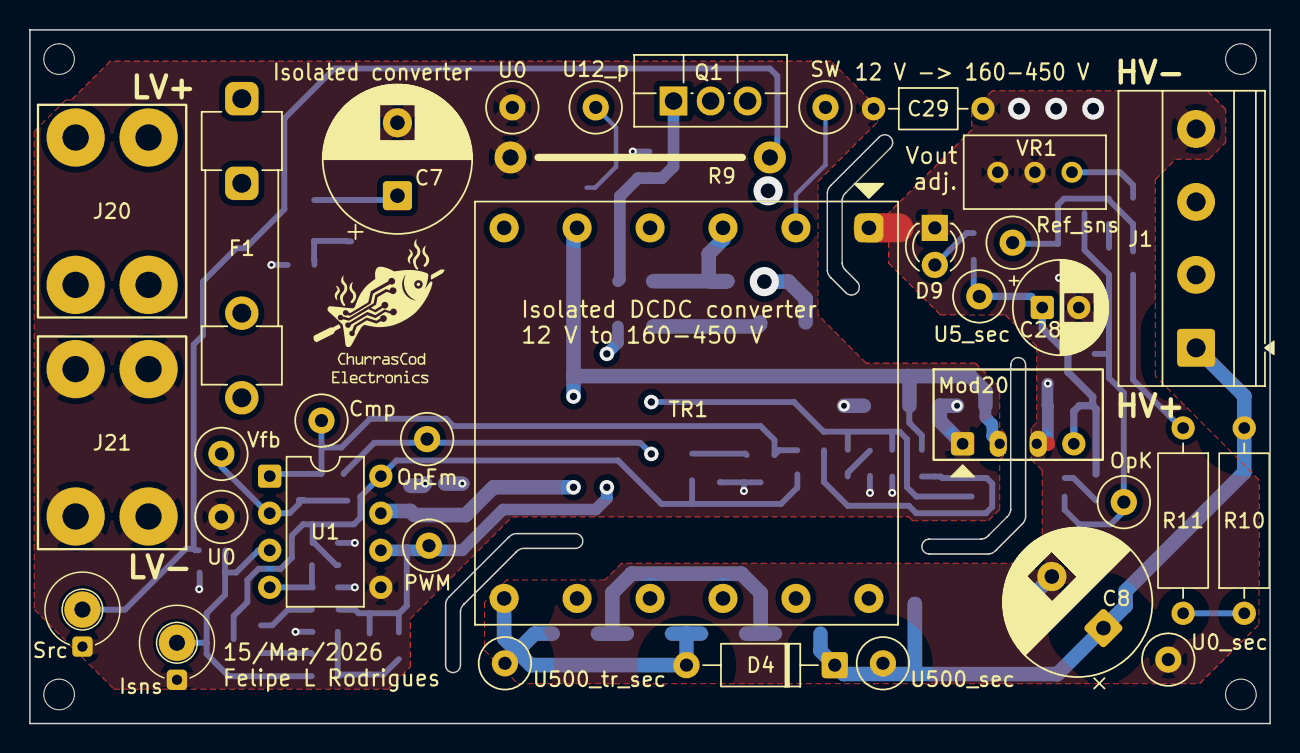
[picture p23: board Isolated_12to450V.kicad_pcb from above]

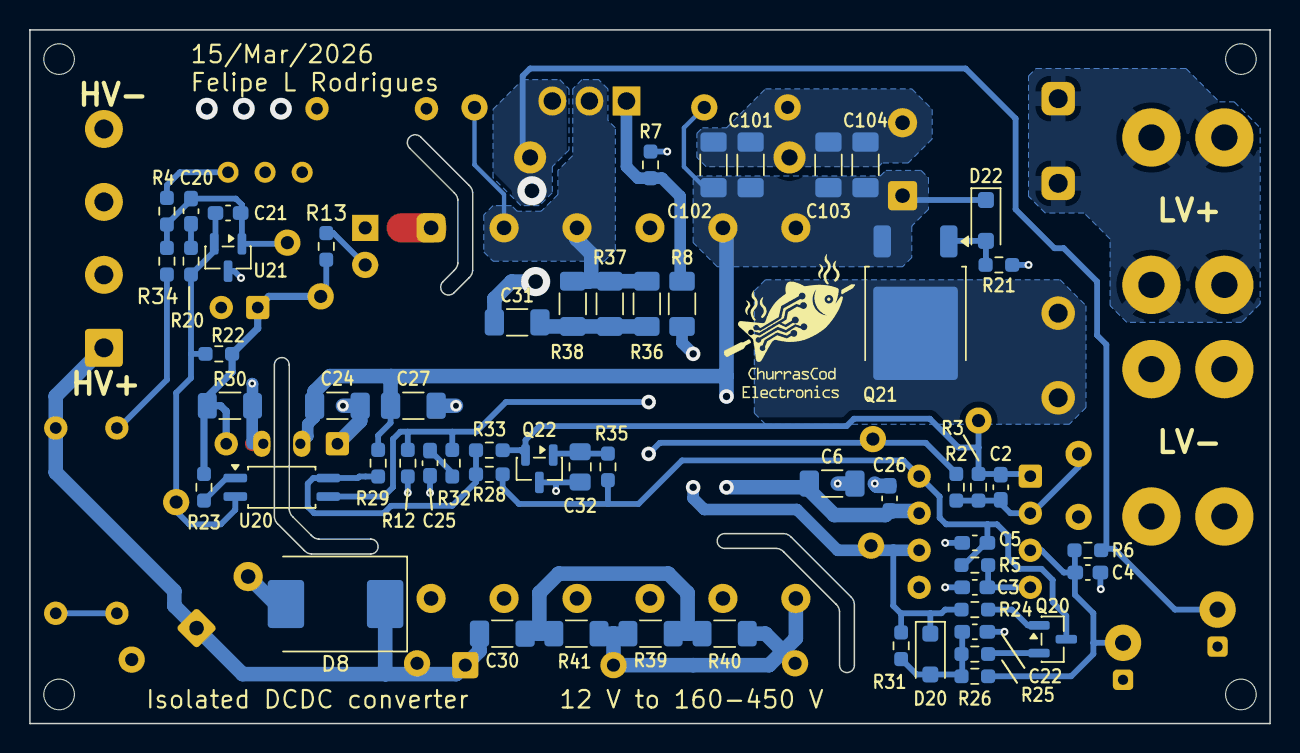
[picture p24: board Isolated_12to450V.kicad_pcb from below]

Board: 4 copper layers, 85.0 x 47.5 mm, 95 parts (57 on the bottom side), 35 nets.

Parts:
C2, C3, C4, C25: 1n; C_0603_1608Metric_Pad1.08x0.95mm_HandSolder
C5, C20, C26: 100n; C_0603_1608Metric_Pad1.08x0.95mm_HandSolder
C6, C24, C27, C101, C102, C103, C104: 4.7u; C_1206_3216Metric_Pad1.33x1.80mm_HandSolder
C7: 1000u; CP_Radial_D10.0mm_P5.00mm
C8: 10u; CP_Radial_D10.0mm_P5.00mm
C21: 100p; C_0603_1608Metric_Pad1.08x0.95mm_HandSolder
C22: 10n; C_0603_1608Metric_Pad1.08x0.95mm_HandSolder
C28: 100u; CP_Radial_D6.3mm_P2.50mm
C29: 1.5n; C_Axial_L3.8mm_D2.6mm_P7.50mm_Horizontal
C30: 220p; C_1206_3216Metric_Pad1.33x1.80mm_HandSolder
C31: 2.7n; C_1206_3216Metric_Pad1.33x1.80mm_HandSolder
C32: 1u; C_0805_2012Metric_Pad1.18x1.45mm_HandSolder
D4: UF4007; D_A-405_P10.16mm_Horizontal
D8: S15M; D_SMC
D9: LED; LED_D3.0mm
D20: PMEG4010CEH; D_SOD-123F
D22: BZT52B15; D_SOD-123F
F1: 10A; Fuse_5x20mm_w_holders
H1, H2, H3, H4: MountingHole; MountingHole_2.1mm
J1: Screw_Terminal_01x04; TerminalBlock_Phoenix_MKDS-1,5-4_1x04_P5.00mm_Horizontal
J20, J21: T44007
Mod20: WB2405S-1W; WB___S-1W
Q1: HY1707; TO-220F-3_Vertical
Q20: BC817; SOT-23
Q21: SUD50P06-15; TO-252-2
Q22: BC857; SOT-23
R2, R3, R21: 10k; R_0603_1608Metric_Pad0.98x0.95mm_HandSolder
R4: 2k7; R_0603_1608Metric_Pad0.98x0.95mm_HandSolder
R5: 15k; R_0603_1608Metric_Pad0.98x0.95mm_HandSolder
R6, R13, R29: 1k; R_0603_1608Metric_Pad0.98x0.95mm_HandSolder
R7: 5k1; R_0603_1608Metric_Pad0.98x0.95mm_HandSolder
R8: 20; R_1206_3216Metric_Pad1.30x1.75mm_HandSolder
R9: 13.7m; Shunt_alixp_module
R10, R11: 240k; R_Axial_DIN0309_L9.0mm_D3.2mm_P12.70mm_Horizontal
R12: 1k2; R_0603_1608Metric_Pad0.98x0.95mm_HandSolder
R20, R35: 100k; R_0603_1608Metric_Pad0.98x0.95mm_HandSolder
R22, R25, R31: 2k2; R_0603_1608Metric_Pad0.98x0.95mm_HandSolder
R23: 470; R_0603_1608Metric_Pad0.98x0.95mm_HandSolder
R24: 4k7; R_0603_1608Metric_Pad0.98x0.95mm_HandSolder
R26: 4.7k; R_0603_1608Metric_Pad0.98x0.95mm_HandSolder
R28, R32, R33, R34: 0; R_0603_1608Metric_Pad0.98x0.95mm_HandSolder
R30, R39, R40, R41: 470; R_1206_3216Metric_Pad1.30x1.75mm_HandSolder
R36, R37, R38: 33; R_1206_3216Metric_Pad1.30x1.75mm_HandSolder
TP9, TP10, TP20, TP23, TP24, TP25, TP26, TP27, TP28, TP30, TP31, TP32, TP33, TP34: TestPoint_Alt; TestPoint_Loop_D3.50mm_Drill0.9mm_Beaded
TP35, TP36: Testpoint_osc_no_lead
TR1: Custom_1:19.5; Tr12to450V_Alixp
U1: UC3845; DIP-8_W7.62mm
U20: TCMT1108; SOP-4_4.4x2.6mm_P1.27mm
U21: TL431M; SOT-23
VR1: 5k; Potentiometer_Bourns_3296W_Vertical

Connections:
/Block Diagram/Schematic/B: Q20.1 (B), R24.2
/Block Diagram/Schematic/Comp: C2.2, Q22.2 (E), R3.2, R33.2, TP25.1, U1.1 (COMP)
/Block Diagram/Schematic/E: Q20.2 (E), R25.2
/Block Diagram/Schematic/Gate: Q1.1 (G), R7.1, R8.2
/Block Diagram/Schematic/Isns: C4.1, R6.1, R26.2, TP35.1 (Sig), U1.3 (ISENSE)
/Block Diagram/Schematic/LED_A_sec: D9.2 (A), R13.2
/Block Diagram/Schematic/OpCol: R28.2, R29.2, R33.1, U20.4
/Block Diagram/Schematic/OpEm: R2.2, R12.1, R32.1, TP26.1, U20.3
/Block Diagram/Schematic/PWM: D20.1 (K), R8.1, R24.1, R31.2, TP23.1, U1.6 (OUTPUT)
/Block Diagram/Schematic/RP_Gate: D22.2 (A), Q21.1 (G), R21.1
/Block Diagram/Schematic/RT_CT: C3.1, R5.1, U1.4 (RT_CT)
/Block Diagram/Schematic/Ramp: C22.1, D20.2 (A), R25.1, R26.1, R31.1
/Block Diagram/Schematic/SW: Q1.2 (D), R36.1, R37.1, R38.1, TP20.1, TR1.2, TR1.3
/Block Diagram/Schematic/Sec_OpA: R23.1, U20.1
/Block Diagram/Schematic/Sec_OpK: C21.2, R20.1, R22.2, TP10.1, U20.2, U21.2 (K)
/Block Diagram/Schematic/Sec_cp_m: C20.2, R20.2
/Block Diagram/Schematic/Sec_div_h: R10.1, R11.2
/Block Diagram/Schematic/Sec_div_l: R4.2, VR1.3
/Block Diagram/Schematic/Sec_div_m: R11.1, R34.1
/Block Diagram/Schematic/Sec_ref_sns: C20.1, C21.1, R4.1, R34.2, TP9.1, U21.1 (REF)
/Block Diagram/Schematic/Src: C31.1, Q1.3 (S), R6.2, R9.1, TP36.1 (Sig)
/Block Diagram/Schematic/U5_ref: C5.1, Q20.3 (C), R5.2, R28.1, R35.1, U1.8 (VREF)
/Block Diagram/Schematic/U5_sec: C28.1, Mod20.4 (Vo+), R13.1, R22.1, R23.2, R30.1, TP34.1
/Block Diagram/Schematic/U12_f: F1.2, Q21.2 (D)
/Block Diagram/Schematic/U12_in: F1.1, J20.1
/Block Diagram/Schematic/U12_p: C6.1, C7.1, C24.1, C26.1, C27.1, C101.1, C102.1, C103.1, C104.1, D22.1 (K), Mod20.2 (Vin+), Q21.3 (S), R29.1, TP31.1, TR1.5, TR1.6, U1.7 (VCC)
/Block Diagram/Schematic/U500_sec: C8.1, C30.2, D4.1 (K), D8.1 (K), J1.1, R10.2, TP27.1
/Block Diagram/Schematic/U500_sn_sec: C30.1, R39.1, R40.1, R41.1
/Block Diagram/Schematic/U500_tr_sec: D4.2 (A), R39.2, R40.2, R41.2, TP30.1, TR1.7
/Block Diagram/Schematic/Vfb: C2.1, R2.1, R3.1, TP24.1, U1.2 (VFB)
unnamed: C25.1, R32.2
unnamed: C31.2, R36.2, R37.2, R38.2
unnamed: C32.1, Q22.1 (B), R35.2
U0: C3.2, C4.2, C5.2, C6.2, C7.2, C22.2, C24.2, C25.2, C26.2, C27.2, C29.1, C32.2, C101.2, C102.2, C103.2, C104.2, J21.1, Mod20.1 (Vin-), Q22.3 (C), R7.2, R9.2, R12.2, R21.2, TP32.1, TP33.1, TP35.2 (Ref), TP36.2 (Ref), U1.5 (GND)
U0_sec: C8.2, C28.2, C29.2, D8.2 (A), D9.1 (K), J1.4, Mod20.3 (0V), R30.2, TP28.1, TR1.1, U21.3 (A), VR1.1, VR1.2

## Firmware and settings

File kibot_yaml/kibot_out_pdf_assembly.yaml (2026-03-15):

# KiBot output for generating Assembly Document in PDF format
# https://kibot.readthedocs.io/en/latest/configuration/outputs/pcb_print.html

kibot:
  version: 1

outputs:
- name: @NAME@
  comment: '@COMMENT@'
  type: pcb_print
  category: '@DIR@'
  dir: '@DIR@'
  options:
    colored_vias: false
    colored_pads: false
    color_theme: '@COLOR_THEME@'
    output: '%f-assembly%I%v.%x'
    format: 'PDF'
    title: '@DOC_TITLE@ Document'
    realistic_solder_mask: false
    dpi: 1200
    dnf_filter: _kibom_dnf_Config
    # dnf_filter: '_null'
    sheet_reference_layout: '@SHEET_WKS@'
    include_table:
      outputs:
        - name: '@NAME_COMP_COUNT@'
          text_alignment: 'left'
          invert_columns_order: false
          border_width: 0.4
          header_rule_width: 0.2
          horizontal_rule_width: 0
          vertical_rule_width: 0
          top_rule_width: 0
          bottom_rule_width: 0
          row_spacing: 3
          column_spacing: 2
    pages:
      - scaling: @SCALING@
        layer_var: ''
        title: '@DOC_TITLE@'
        sheet: Top/Bottom View
        sheet_reference_color: '#000000'
        layers:
          - layer: '@LAYER_TITLE_PAGE@'
            color: '#000000'

      - scaling: @SCALING@
        layer_var: "Top Assembly (Scale @SCALING@:1)"
        title: '@DOC_TITLE@'
        sheet: Top Assembly (Scale @SCALING@:1)
        sheet_reference_color: '#000000'
        colored_holes: true
        holes_color: "#FFFFFF"
        layers:
          - layer: Edge.Cuts
            color: '#000000'
          - layer: F.Cu
            color: '#EEDAB5'
          - layer: F.Mask
            color: '#B9B9B9'
          - layer: F.Paste
            color: '#E1A98E'
         # - layer: F.Silkscreen
         #   color: '#DB9DE1'
          - layer: F.Fab
            exclude_filter: '@FAB_EXCLUDE_FILTER@'
            color: '#744679'
          - layer: '@LAYER_ASSEMBLY_TEXT_TOP@'
            color: '#000000'
          - layer: '@LAYER_DNP_CROSS_TOP@'
            color: '#D63034'

      - scaling: @SCALING@
        layer_var: "Bottom Assembly (Scale @SCALING@:1)"
        mirror: true
        mirror_pcb_text: true #test
        title: '@DOC_TITLE@'
        sheet: Bottom Assembly (Scale @SCALING@:1)
        sheet_reference_color: '#000000'
        colored_holes: true
        holes_color: "#FFFFFF"
        layers:
          - layer: Edge.Cuts
            color: '#000000'
          - layer: B.Cu
            color: '#D5DBF4'
          - layer: B.Mask
            color: '#B9B9B9'
          - layer: B.Paste
            color: '#BCB9DD'
         # - layer: B.Silkscreen
         #   color: '#DB9DE1'
          - layer: B.Fab
            exclude_filter: '@FAB_EXCLUDE_FILTER@'
            color: '#400080'
          - layer: '@LAYER_ASSEMBLY_TEXT_BOTTOM@'
            color: '#000000'
          - layer: '@LAYER_DNP_CROSS_BOTTOM@'
            color: '#D63034'

...
definitions:
  NAME: pdf_assembly
  COMMENT: Assembly document in PDF format
  DIR: Manufacturing/Assembly
  DOC_TITLE: Assembly
  COLOR_THEME: Altium_Theme
  SHEET_WKS: ${KIPRJMOD}/Templates/KDT_Template_PCB_GIT_A4.kicad_wks
  SCALING: 1.0
  FAB_EXCLUDE_FILTER: exclude_testpoints
  LAYER_TITLE_PAGE: TitlePage
  LAYER_ASSEMBLY_TEXT_TOP: F.AssemblyText
  LAYER_ASSEMBLY_TEXT_BOTTOM: B.AssemblyText
  LAYER_DNP_CROSS_TOP: F.DNP
  LAYER_DNP_CROSS_BOTTOM: B.DNP
  NAME_COMP_COUNT: csv_comp_count

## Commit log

2025-12-30 Initial commit, no junk
    [Block Diagram.kicad_sch, Isolated_12to450V.kicad_sch, Revision History.kicad_sch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]
2025-12-30 Update Outputs
    [Isolated_12to450V-bom.csv]
2026-01-03 Sch and PCB ready, using existing PCB as basis w aux PCB for new parts
    [Block Diagram.kicad_sch, Isolated_12to450V.kicad_sch, Schematic.kicad_sch]
2026-01-03 Updated state and changelog, fixed DRC issues
    [Schematic.kicad_sch]
2026-01-04 Minor schematic changes (arrangement only)
    [Schematic.kicad_sch]
2026-01-24 First working prototype - still not isolated
    [Revision History.kicad_sch, Schematic.kicad_sch]
2026-01-24 First working prototype - still not isolated, ERC and DRC clear
2026-01-24 Update Outputs (release)
    [Isolated_12to450V.step]
2026-01-26 Schematic topology completed, adjusting packages
    [Schematic.kicad_sch]
2026-01-27 Several footprint updates
    [Schematic.kicad_sch]
2026-01-28 Layout started
    [Schematic.kicad_sch]
2026-01-28 Layout candidate drafted
    [Schematic.kicad_sch]
2026-01-28 Layout candidate #2 (draft)
    [Schematic.kicad_sch]
2026-01-30 Layout in progress, added some rules and net classes
    [Schematic.kicad_sch]
2026-01-31 All rules added, ready to start routing
    [Schematic.kicad_sch]
2026-02-01 Routing complete
    [Schematic.kicad_sch]
2026-02-01 Libraries added, revision notes and readme updated
    [Isolated_12to450V.kicad_pcb, Revision History.kicad_sch, Schematic.kicad_sch]
2026-02-02 Added other design into PCB to take advantage of 100 x 100 mm limit from JLCPCB
    [Schematic.kicad_sch]
2026-02-03 Investigating CI failure, no design changes
    [Schematic.kicad_sch]
2026-02-04 Layout rework in progress after checking paper mock up
    [Schematic.kicad_sch]
2026-02-05 Layout ready and checked
    [Schematic.kicad_sch]
2026-02-06 Minor changes to resolve potential DFM issues flagged by JLCPCB
    [Schematic.kicad_sch]
2026-02-06 Updated paths on footprint libraries to render 3D models on KiBot
2026-02-06 Removed extra prototyping area and started updating mfg docs
    [Schematic.kicad_sch]
2026-02-06 fixing templates
    [Isolated_12to450V.kicad_pcb]
2026-02-06 resolving ci failure
    [Isolated_12to450V.kicad_pcb]
2026-02-06 de-embedding pcb sheet template
2026-02-07 changed grid origin pos.
    [Block Diagram.kicad_sch, Isolated_12to450V.kicad_pcb, Isolated_12to450V.kicad_sch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]
2026-02-07 Tweaking yaml for mfg files
    [Block Diagram.kicad_sch, Isolated_12to450V.kicad_sch, Revision History.kicad_sch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]
2026-02-07 Changed status to CHECKED, minor tweaks to mfg layers
    [Isolated_12to450V.kicad_pcb]
2026-02-07 Preparing release
    [Block Diagram.kicad_sch, Isolated_12to450V.kicad_sch, Revision History.kicad_sch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]
2026-02-07 Rev hist comments updated
    [Revision History.kicad_sch]
2026-03-10 Sch update ongoing
    [Isolated_12to450V.kicad_pcb, Schematic.kicad_sch]
2026-03-10 Further sch changes
    [Schematic.kicad_sch]
2026-03-12 Schematic nearly complete
    [Isolated_12to450V.kicad_pcb, Schematic.kicad_sch]
2026-03-13 added perfboard
    [Block Diagram.kicad_sch, PerfBoard.kicad_sch, Schematic.kicad_sch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]
2026-03-14 layout update started
    [Isolated_12to450V.kicad_sch, Schematic.kicad_sch]
2026-03-14 ERC/DRC completed
    [PerfBoard.kicad_sch]
2026-03-14 Updating mfg drw
    [Schematic.kicad_sch]
2026-03-15 Updated rev history
    [Revision History.kicad_sch, Schematic.kicad_sch, calc.xlsx]
2026-03-15 another attempt to update rev hist
    [calc.xlsx]
2026-03-15 testing readme fix
    [Isolated_12to450V.kicad_sch]
2026-03-31 Trying linux setup
    [Schematic.kicad_sch]
2026-03-31 Removed perfboard, new branch on linux
    [Block Diagram.kicad_sch]
2026-03-31 trying no verbose on log output
    [Schematic.kicad_sch]
2026-03-31 trying to disable kiri
    [Schematic.kicad_sch]
2026-03-31 KiRi to gitignore
    [Schematic.kicad_sch]
2026-03-31 Added power on LED
    [Isolated_12to450V.kicad_pcb, Schematic.kicad_sch]
2026-03-31 Updated changelog
    [Revision History.kicad_sch, Schematic.kicad_sch]
2026-03-31 updated supporting spreadsheet
    [Schematic.kicad_sch, calc.xlsx]
2026-03-31 fixing pre set variables
    [Schematic.kicad_sch]
